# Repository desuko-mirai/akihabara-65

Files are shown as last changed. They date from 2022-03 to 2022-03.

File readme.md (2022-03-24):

# Akihabara 65 v0.4

### A 65% keyboard designed for JIS layout, with ANSI and ISO support.

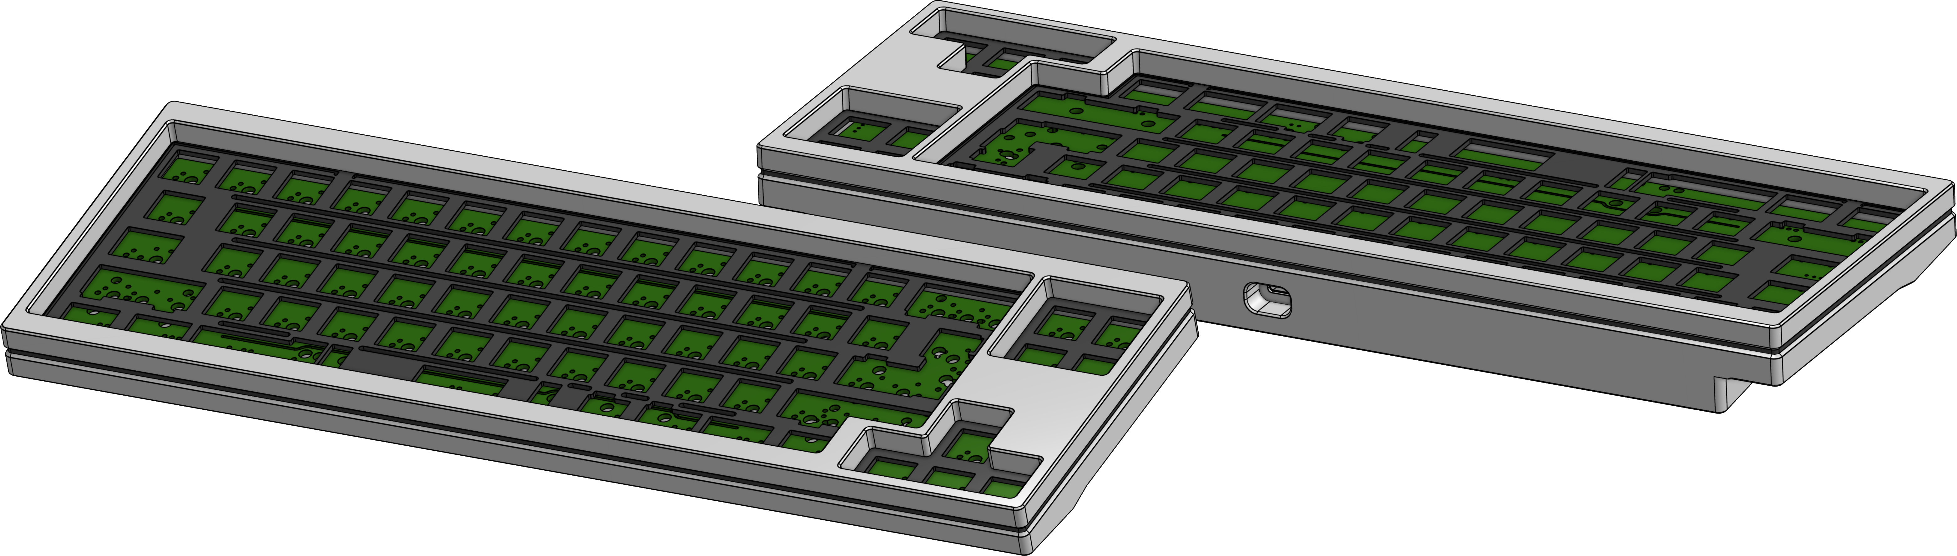
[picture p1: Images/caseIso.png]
Case Isometric


## Design Overview & Features

### Case

- 7° typing angle
- Modified sandwich mount
- 19 mm front height, 13.3 mm plate height @ bottom row, 22.6 mm plate height @ top row, all measurements with feet
- [SKUF](https://github.com/Zambumon/SKUF) Feet
- Approximately 1050 g with aluminium plate
- Exposed plate edges
- Plate features four rows of flex cuts, and the primary key cluster is separated from the plate save for four "mounting points" in an attempt to soften the harshness associated with sandwich mount
- 9.525 mm top and bottom bezels, 4.7625 mm side bezels
- 339 x 116 x 31 mm

### PCB

- Designed for STM32F072, but should be compatible with other STM32 models
- [Unified C3](https://github.com/ai03-2725/Unified-Daughterboard) Daughterboard
- QMK & VIA in progress
- PCB designed with KiCAD 6
- Bottom row legend; no more guessing where to place your switches and stabilizers
- Two flex cuts

## Layouts

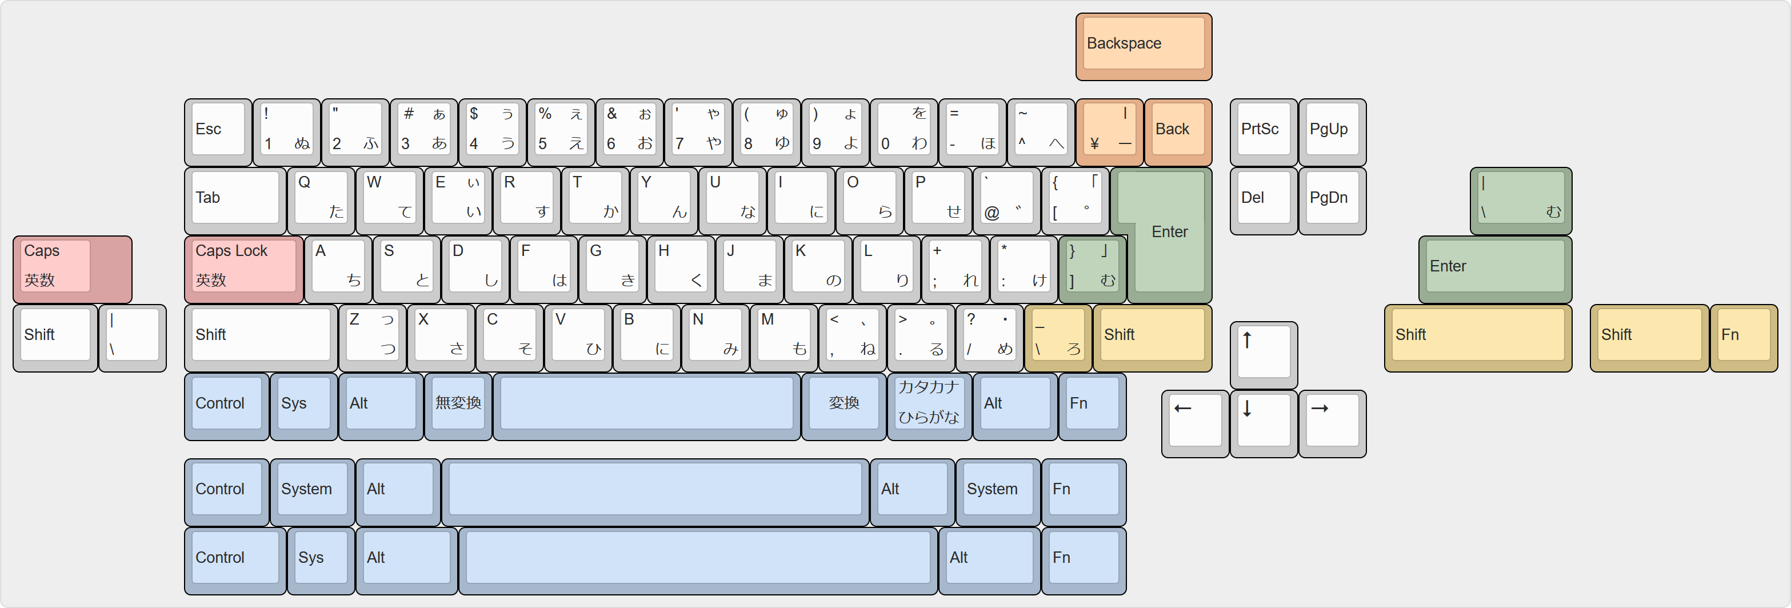
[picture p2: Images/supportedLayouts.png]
Supported Layouts


The Akihabara 65 was designed for a JIS layout with a 4.5u spacebar, but it supports many layouts. Options include:

- Standard or Stepped Caps Lock
- Standard or Split Backspace
- 2.75u or Split Right Shift (1.75u | 1u **OR** 1u | 1.75u)
- ANSI or ISO/JIS Enter
- 4.5u, 6.25u, or 7u Bottom Row

## Supported Keycap Sets

Almost all sets will support ANSI, and many support ISO as well, however JIS is significantly less common amongst custom keyboard enthusiasts, even in Japan. Still, keycap sets with JIS compatibility do exist. Known sets include:

- [ePBT SimpleJA R2](https://geekhack.org/index.php?topic=114422.0)[^kitting][^spacebar] by ai03
- [ePBT ModernJA](https://geekhack.org/index.php?topic=109341.0)[^kitting][^spacebar] by ai03
- [TMT Story](https://geekhack.org/index.php?topic=112681.0)[^gb] by shawnlyx/lunasho
- [GMK JIS](https://geekhack.org/index.php?topic=108328.0)[^gb] by 2Moons
- [Majestouch Keycaps](https://www.diatec.co.jp/products/list.php?s[]=100:1002:10008)[^fn] by FILCO/DIATEC

[^kitting]: Requires JIS/ISO kit
[^spacebar]: Does not include 4.5u spacebar
[^gb]: Group buy not yet fulfilled
[^fn]: Does not inclue R4 1u Fn key; can substitute with Menu key

### 4.5u Keycaps & Stabilizers

Outside of Japan, 4.5u spacebars are very uncommon; even more so in the quality we expect in this hobby. The selection is very limited, but not completely nonexistent.

The easiest way to acquire a 4.5u spacebar is to purchase one from KPRepublic [here](https://kprepublic.com/products/xda-blank-convex-spacebar-grey-1-75u-2u-2-25u-2-75u-3u-4-5u-5-5u-6u-6-25u-6-5u-7u-blank-keycaps-for-xd60-xd64-xd84-xd75-gh60-60). Unfortunately, these only come in grey PBT in XDA profile. An XDA spacebar does not look too out of place amongst Cherry-profile keycaps, and being PBT you can theoretically dye it. Signature Plastics also produces 4.5u spacebars in their SA profile, but these are unfortunately not sold on PMK, so acquiring one might prove difficult. TomatoCaps has a 4.5u spacebar mold, as seen in TMT Story. GMK will also have a 4.5u spacebar mold some time in 2022.

The only place I have found that sells 4.5u stabilizers is NPKC RGB CP Store on AliExpress. I purchased mine from their store [here](https://www.aliexpress.com/item/32855603554.html); just leave the seller a message on checkout saying you want 4.5u wires instead of 6.25u. I believe they will also sell you the wires by themselves; the housings are not very good at all, so this route may be preferable.

You can also make a 4.5u wire yourself by cutting and bending a 6.25u or 7u wire (or any wire longer than 4.5u). The centre-to-centre distance of the stabilizer mounts on a 4.5u spacebar is 69.342 mm. It is difficult to get the bend radius tight without a wire bender, but that still did not cause any issues with the Durock wire I bent.

## And A Big "Thank You" To:

- **kkatano** for the [Bakeneko](https://github.com/kkatano/bakeneko-65), from which I took many design elements for the case (and it's also just a really nice keyboard)
- **4pplet** and **Gondolindrim** for sharing their knowledge of ARM-powered keyboards in a world filled with AVR
- **ai03** for their brilliant [plate generator](https://kbplate.ai03.com/) and [keyswitch footprints](https://github.com/ai03-2725/MX_Alps_Hybrid), as well as their [PCB design guide](https://wiki.ai03.com/books/pcb-design)
- **hadi** for their [PCB design series](https://www.youtube.com/watch?v=BhFqkVggv8Q), unfinished as it may be
- **2Moons** for helping me confirm dimensions for 4.5u spacebars

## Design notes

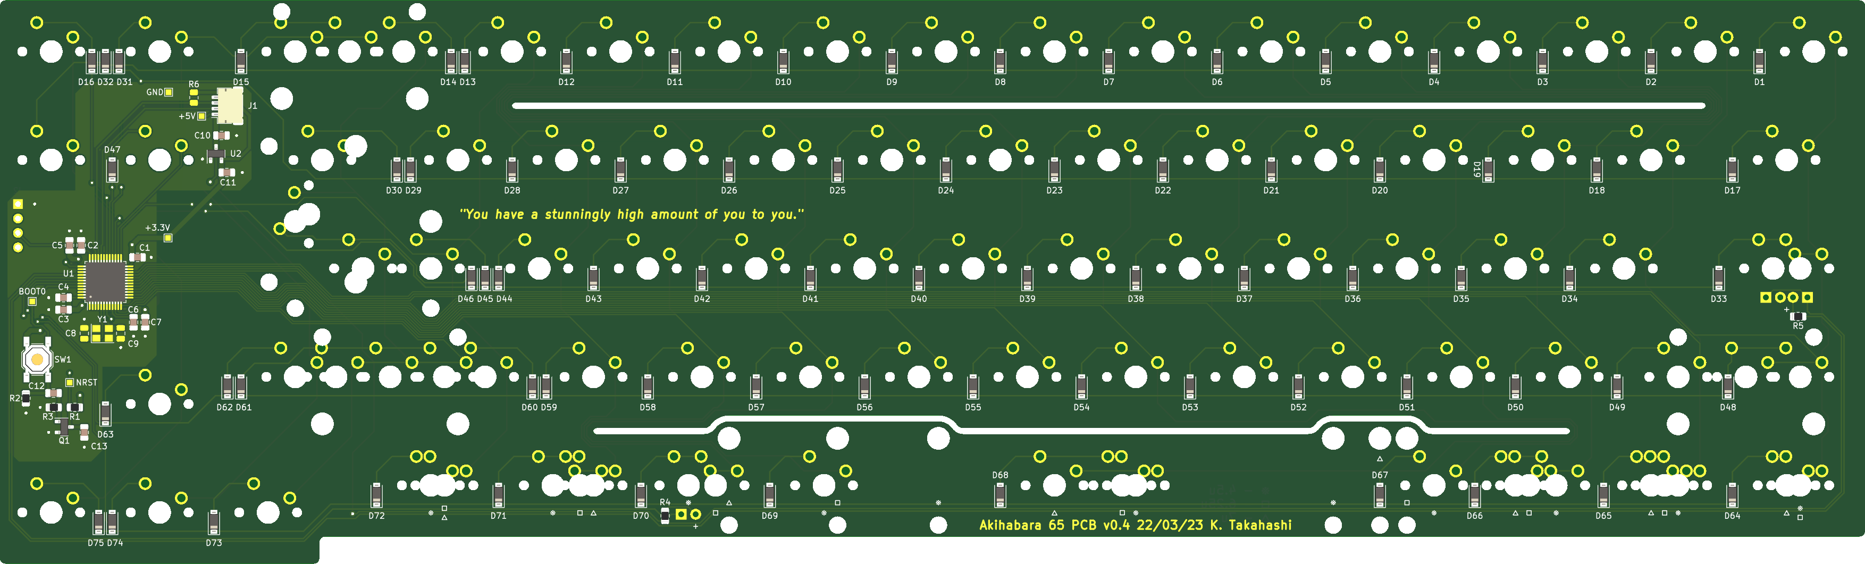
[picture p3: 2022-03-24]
Images/boardBack.png

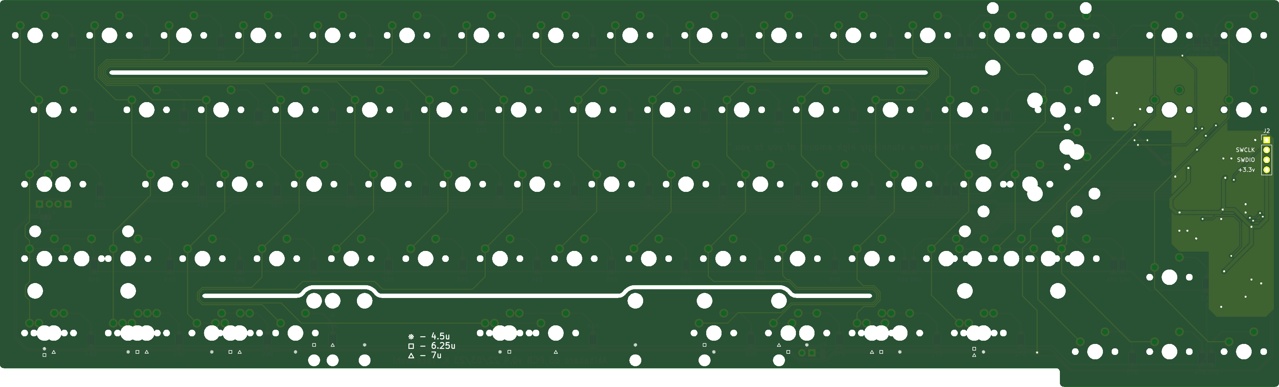
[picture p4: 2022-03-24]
Images/boardFront.png

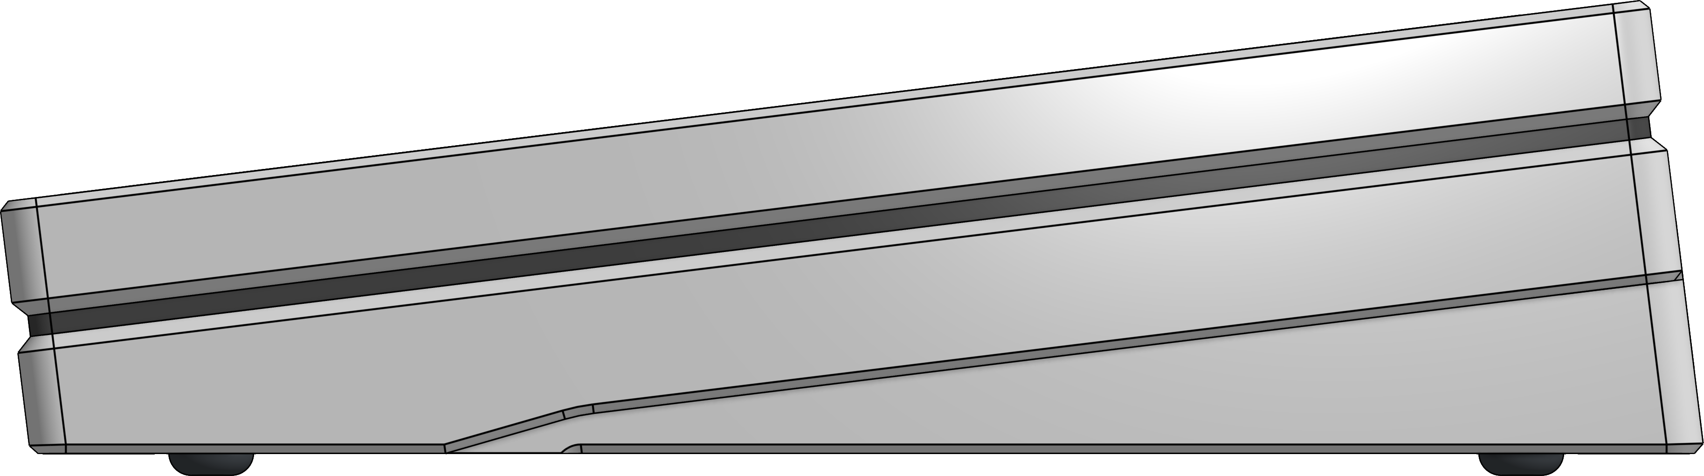
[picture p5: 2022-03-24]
Images/caseSide.png

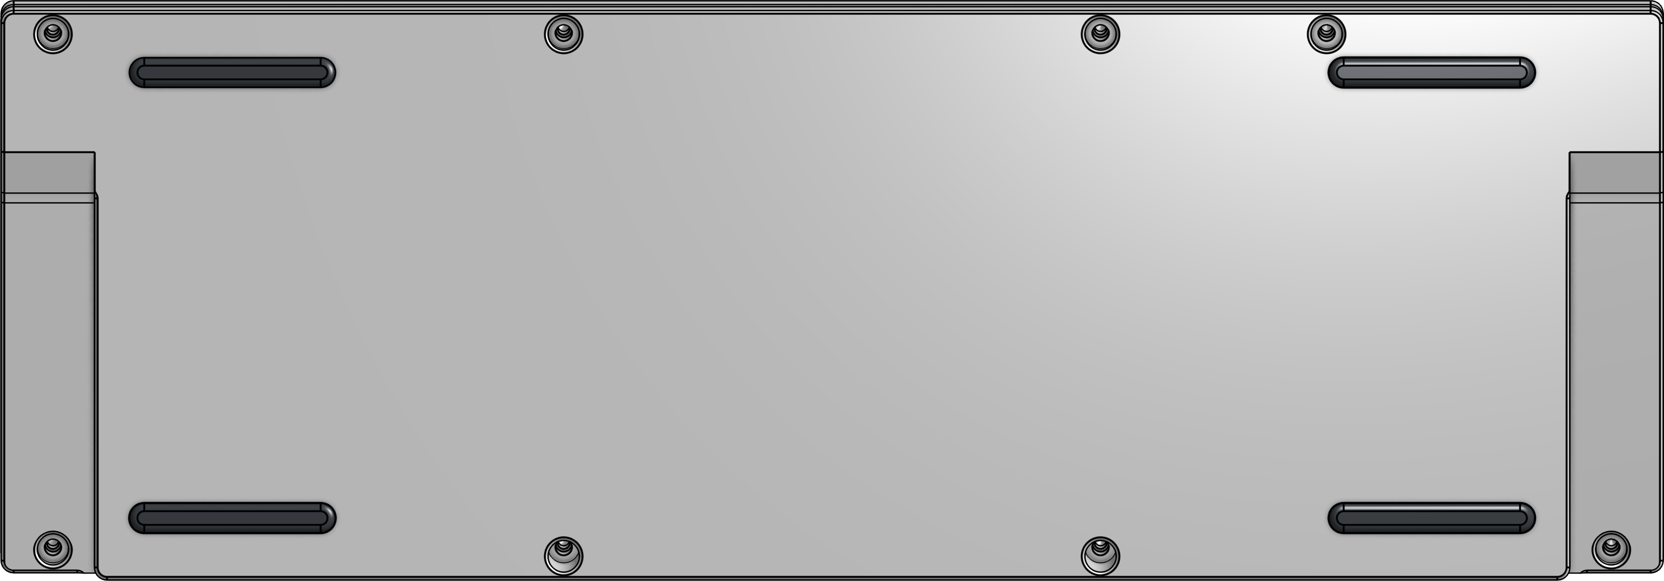
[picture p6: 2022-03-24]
Images/caseBottom.png

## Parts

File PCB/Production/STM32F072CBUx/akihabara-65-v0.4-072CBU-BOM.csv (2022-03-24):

Comment | Designator | Footprint | LCSC
100nF | C1,C2,C3 | Capacitor_SMD:C_0805_2012Metric | C28233
4.7uF | C4,C5,C12 | Capacitor_SMD:C_0805_2012Metric | C1779
10nF | C6 | Capacitor_SMD:C_0805_2012Metric | C1710
1uF | C7,C10,C11,C13 | Capacitor_SMD:C_0805_2012Metric | C28323
1N4148W | D1,D2,D3,D4,D5,D6,D7,D8,D9,D10,D11,D12,D13,D14,D15,D16,D17,D18,D19,D20,D21,D22,D23,D24,D25,D26,D27,D28,D29,D30,D31,D32,D33,D34,D35,D36,D37,D38,D39,D40,D41,D42,D43,D44,D45,D46,D47,D48,D49,D50,D51,D52,D53,D54,D55,D56,D57,D58,D59,D60,D61,D62,D63,D64,D65,D66,D67,D68,D69,D70,D71,D72,D73,D74,D75 | Diode_SMD:D_SOD-123 | C81598
SM04B-SRSS-TB(LF)(SN) | J1 | Connector_JST:JST_SH_SM04B-SRSS-TB_1x04-1MP_P1.00mm_Horizontal | C160404
2N7002 | Q1 | Package_TO_SOT_SMD:SOT-23 | C8545
10k | R1,R2 | Resistor_SMD:R_0805_2012Metric | C17414
100k | R3 | Resistor_SMD:R_0805_2012Metric | C17407
220 | R4,R5 | Resistor_SMD:R_0805_2012Metric | C17557
TS-1187A-B-A-B | SW1 | Button_Switch_SMD:SW_SPST_TL3342 | C318884
STM32F072CBU6 | U1 | Akihabara_Footprints:STM32_CxT_CxU_Hybrid | C92504
XC6206P332MR | U2 | Package_TO_SOT_SMD:SOT-23 | C5446

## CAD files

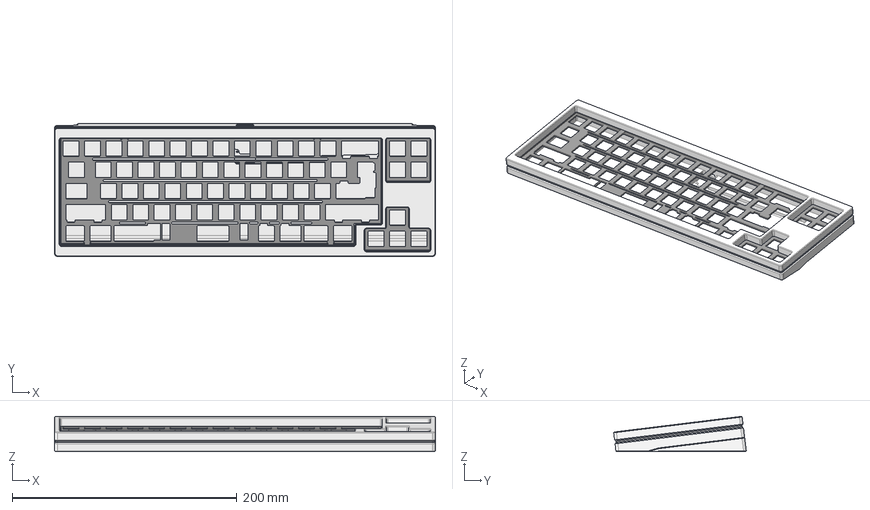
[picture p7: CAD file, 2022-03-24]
Case/akihabara-65-case-assembly-v0.4.step
339.1 x 118.1 x 31.3 mm
Plate
Case Top
Case Bottom

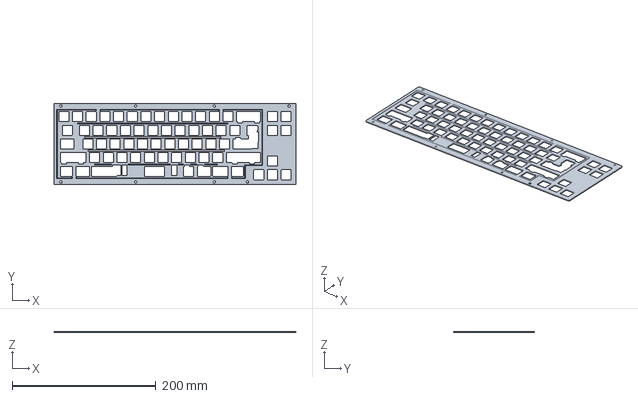
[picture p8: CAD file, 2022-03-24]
Plate/akihabara-65-plate-universal-v0.4.step
337.1 x 113.2 x 1.50 mm

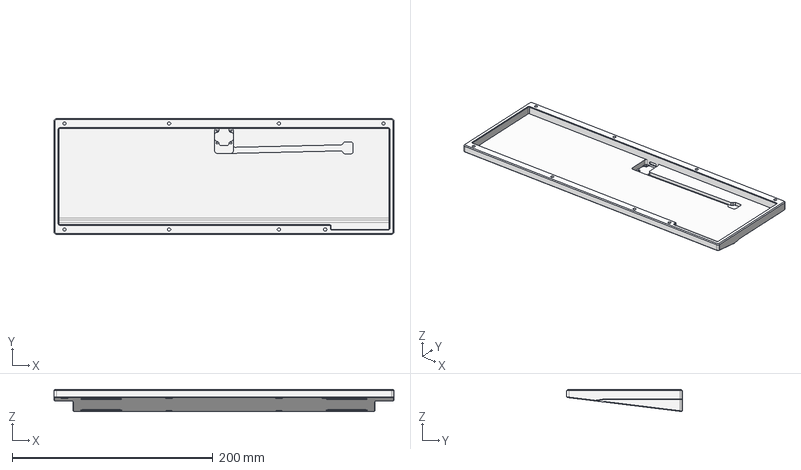
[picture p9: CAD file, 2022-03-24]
Case/akihabara-65-case-bottom-v0.4.step
339.1 x 115.2 x 22.1 mm

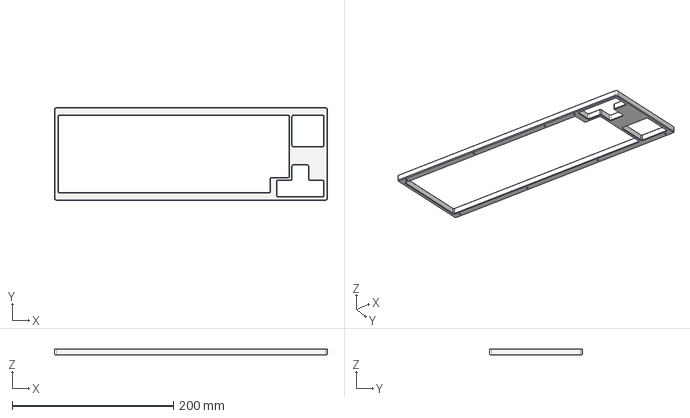
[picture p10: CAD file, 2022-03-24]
Case/akihabara-65-case-top-v0.4.step
339.1 x 115.2 x 8.00 mm

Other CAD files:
Plate/akihabara-65-plate-universal-v0.4.dxf

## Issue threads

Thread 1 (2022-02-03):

Stabilizer holes too small

desuko-mirai, 2022-02-03:
The larger of the two holes used to mount the stabilizers are too small, making inserting the stabilizer excessively difficult.

desuko-mirai, 2022-03-17:
Holes are correct and follow Cherry specifications; this was an issue caused by Durock stabs.

Closed 2022-03-17.

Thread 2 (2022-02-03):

ANSI Enter and Right Shift stabilizers mutually exclusive

desuko-mirai, 2022-02-03:
The ANSI Enter stabilizer is wire-down and the Right Shift stabilizer is wire-up, causing interference between the two stabilizers. Both stabilizers will be wire-down in v0.4.

desuko-mirai, 2022-03-17:
v0.4 now has north-facing ANSI Enter wire and south-facing Right Shift wire.

Closed 2022-03-17.

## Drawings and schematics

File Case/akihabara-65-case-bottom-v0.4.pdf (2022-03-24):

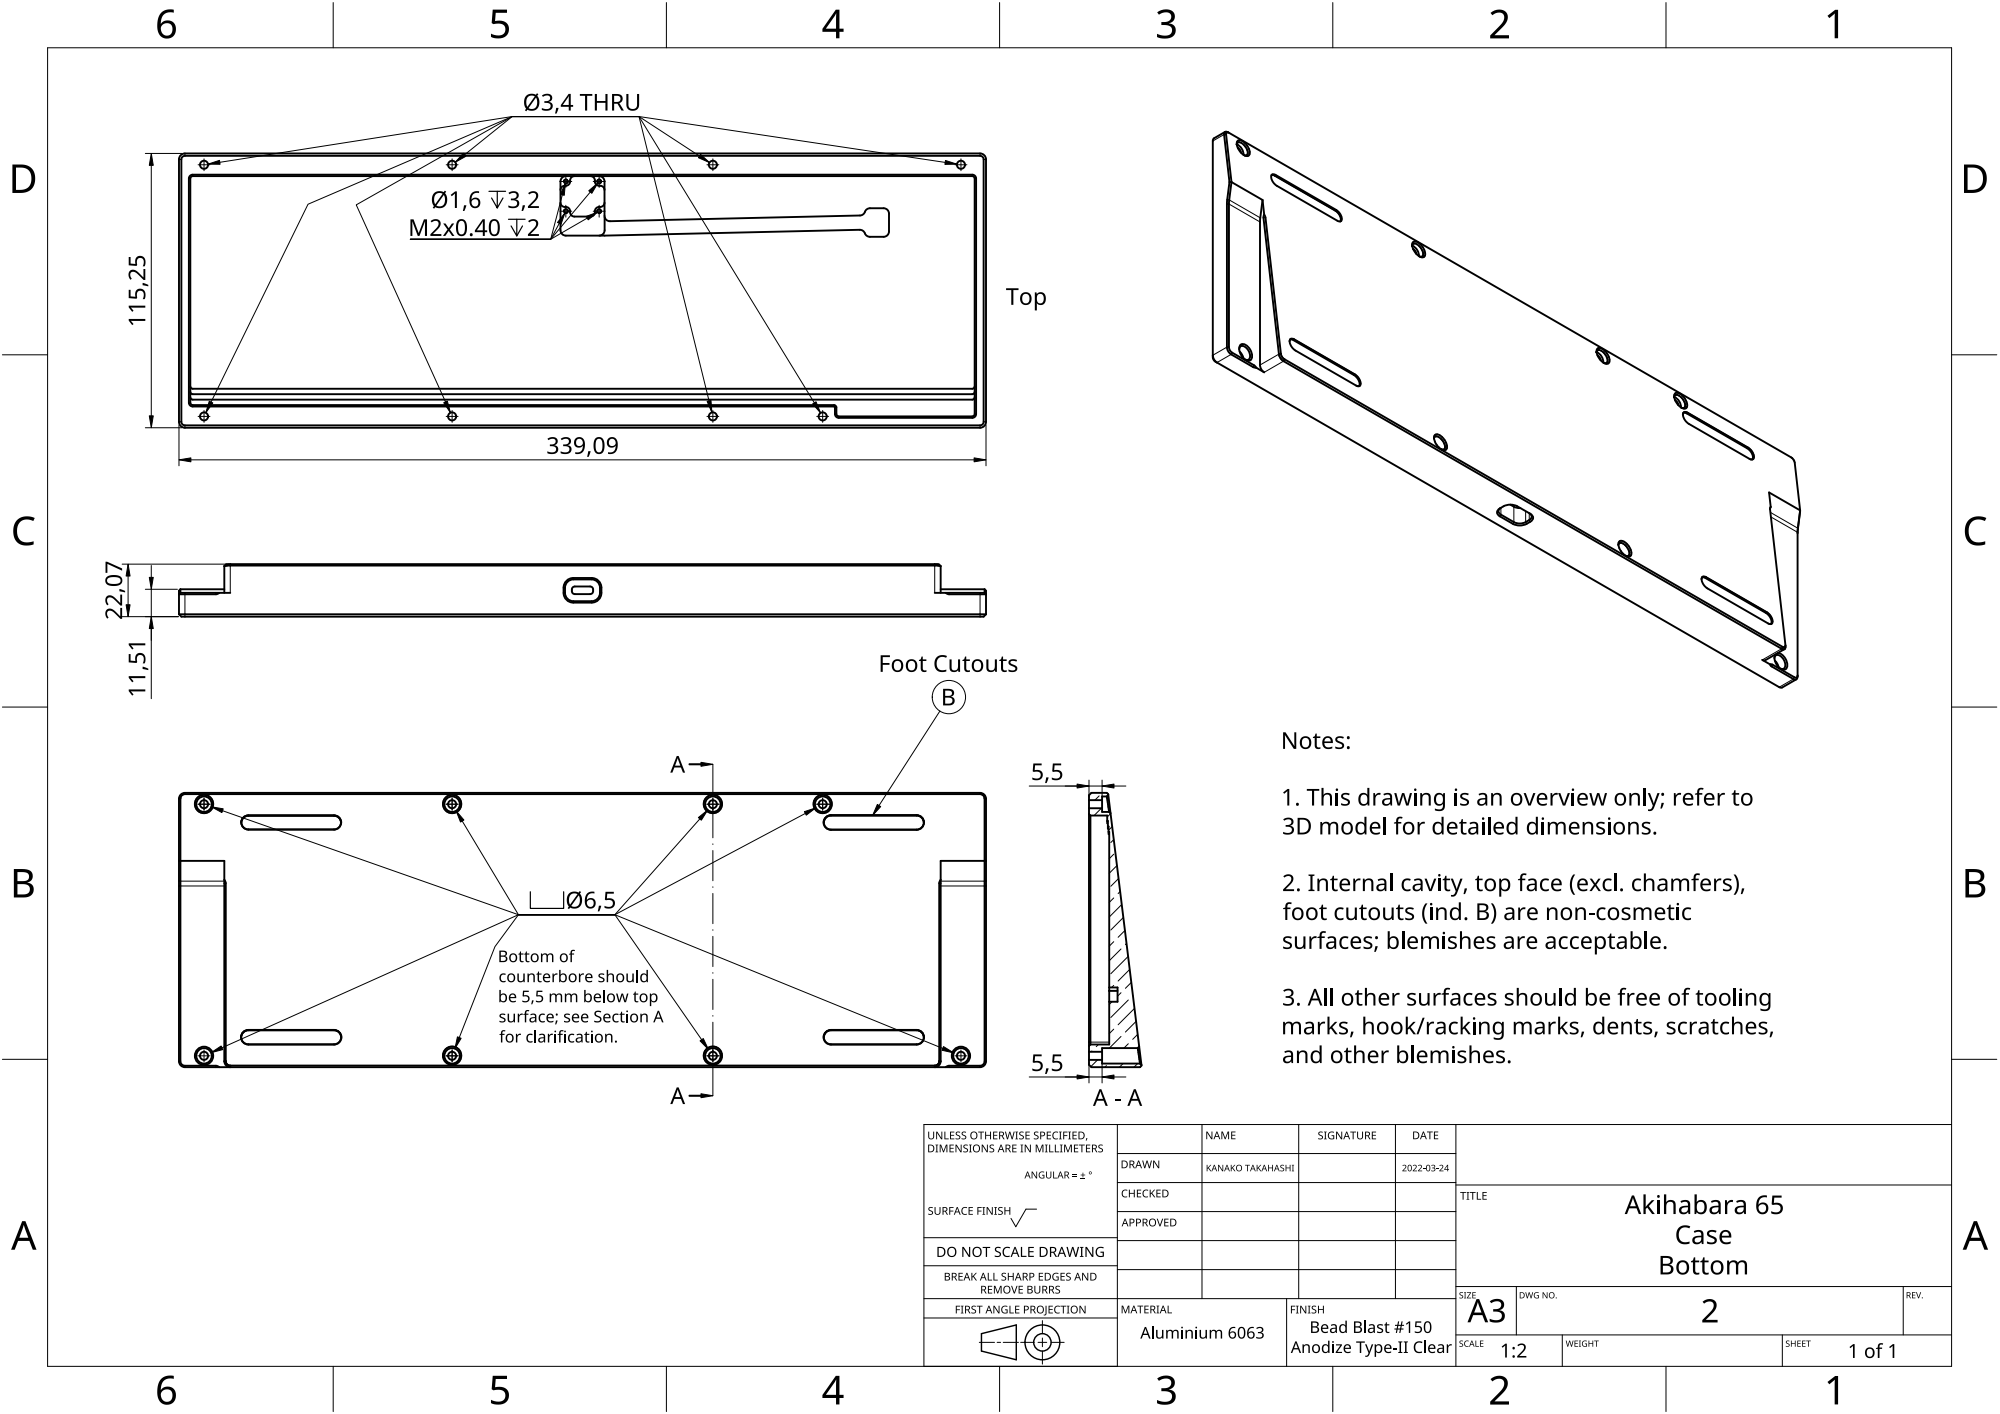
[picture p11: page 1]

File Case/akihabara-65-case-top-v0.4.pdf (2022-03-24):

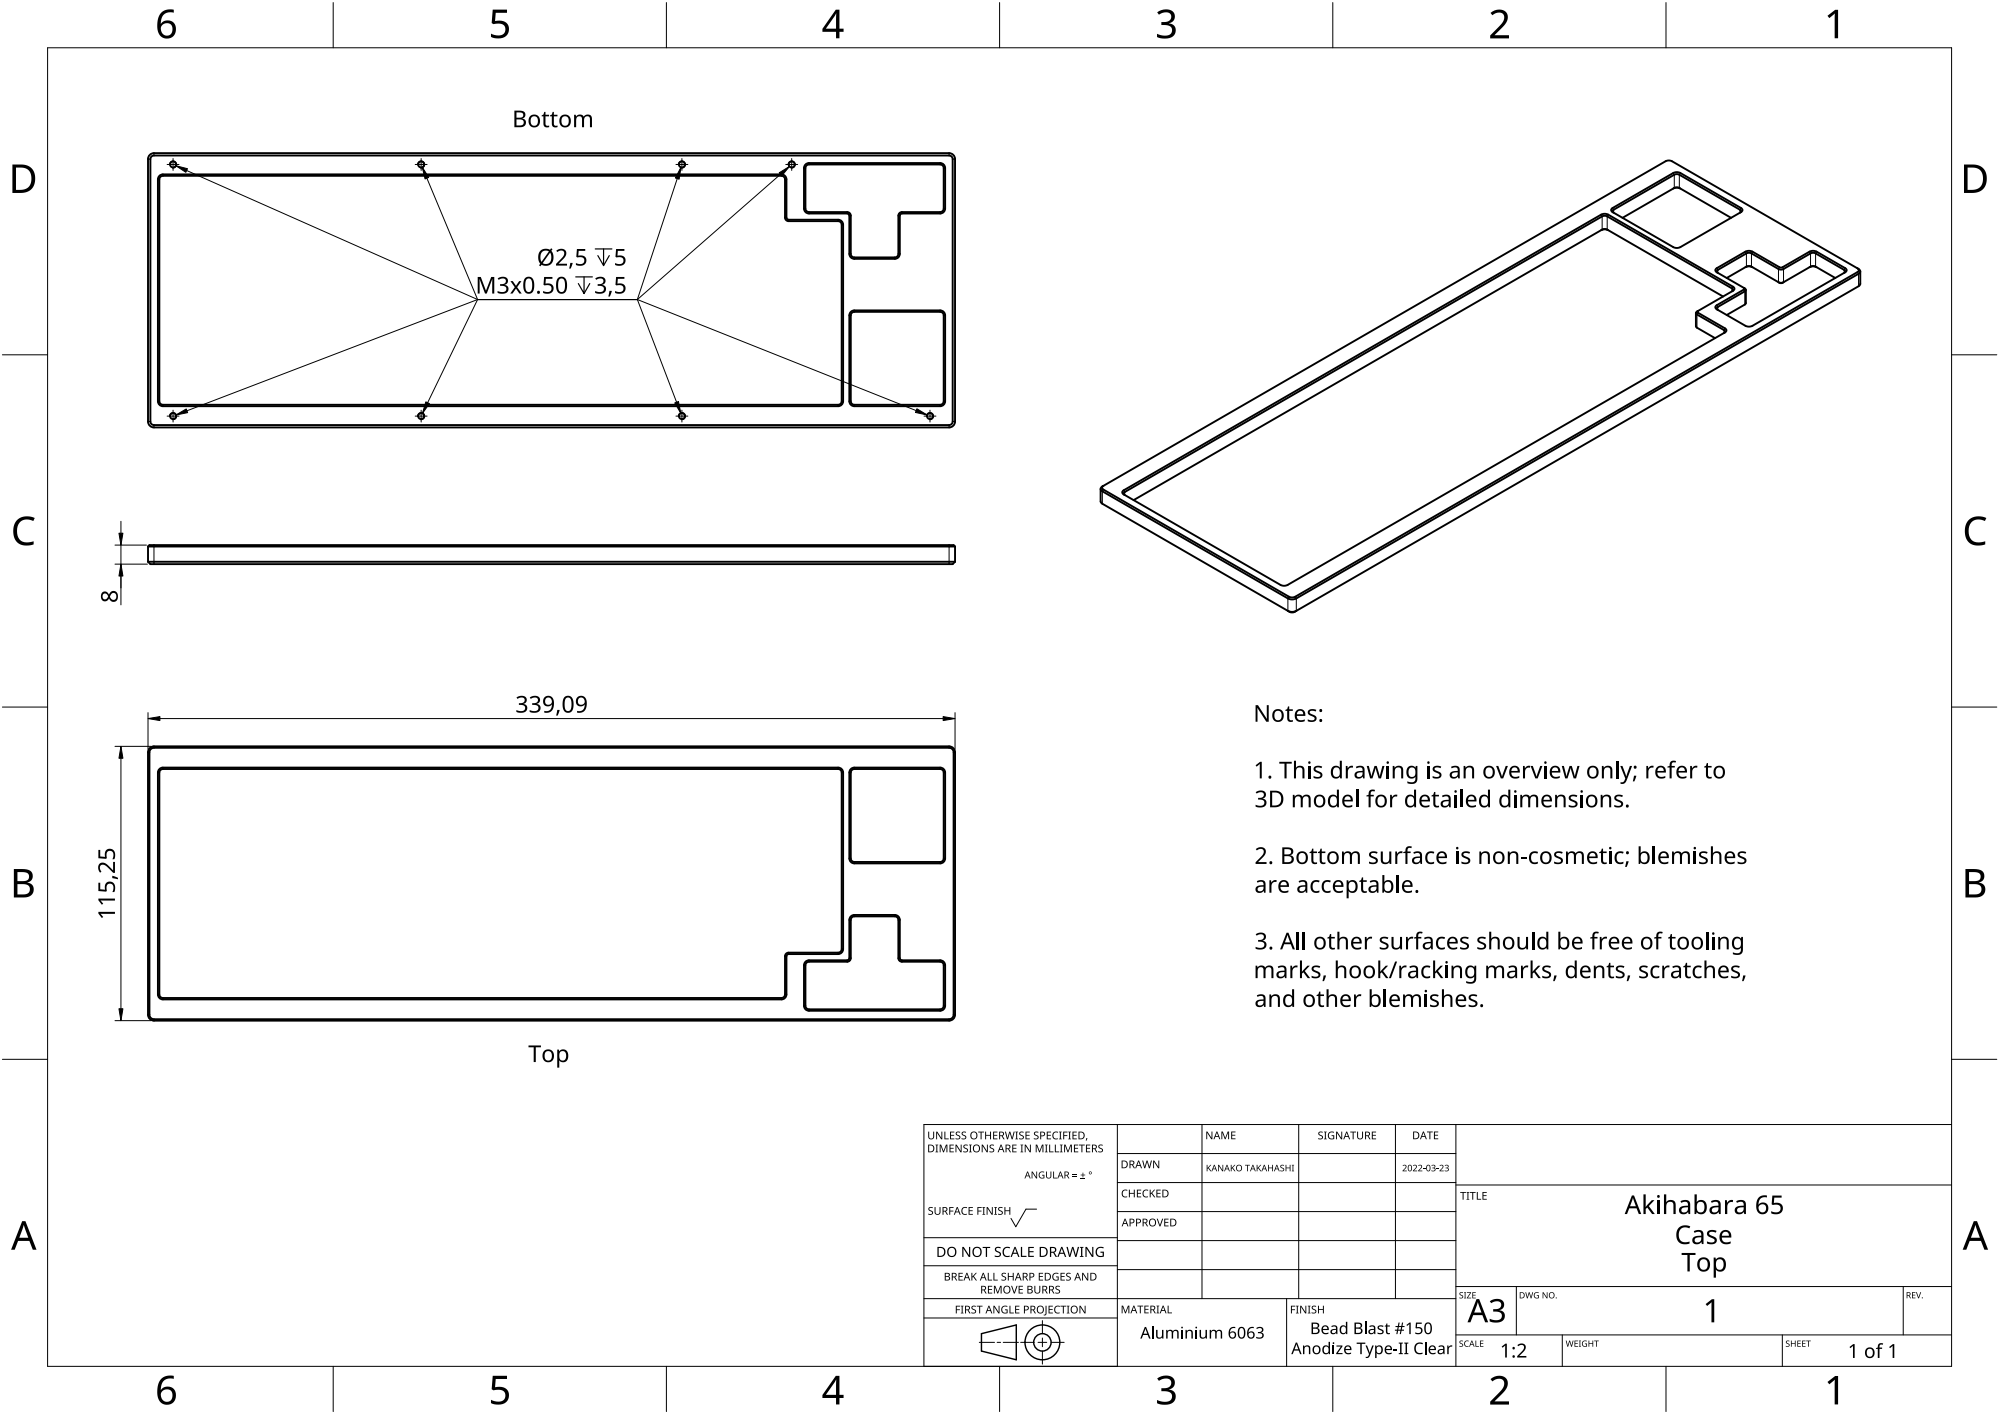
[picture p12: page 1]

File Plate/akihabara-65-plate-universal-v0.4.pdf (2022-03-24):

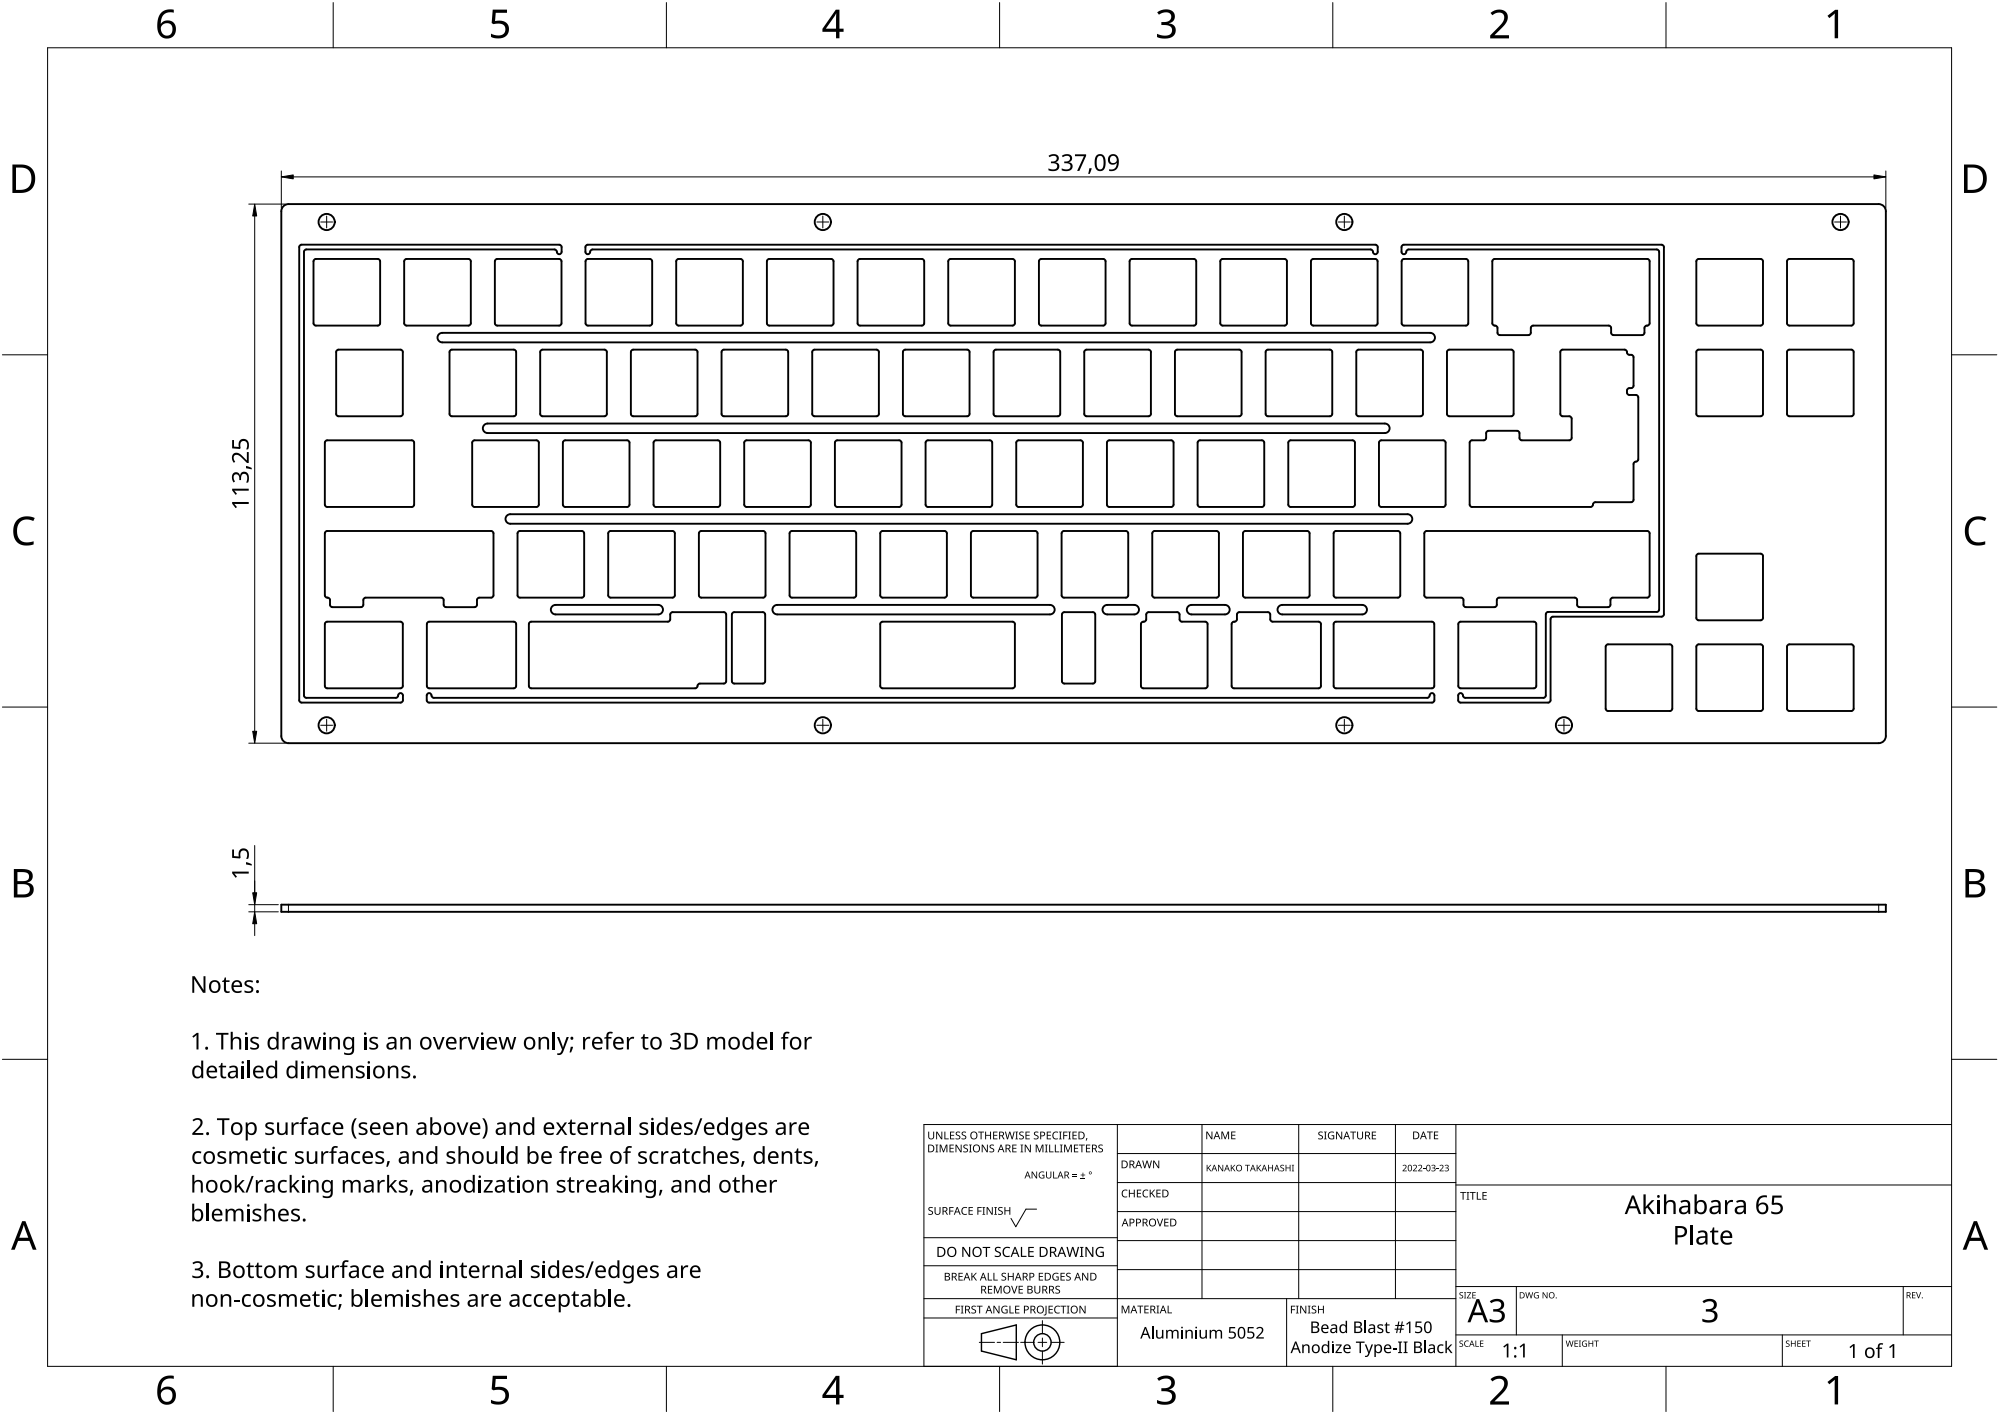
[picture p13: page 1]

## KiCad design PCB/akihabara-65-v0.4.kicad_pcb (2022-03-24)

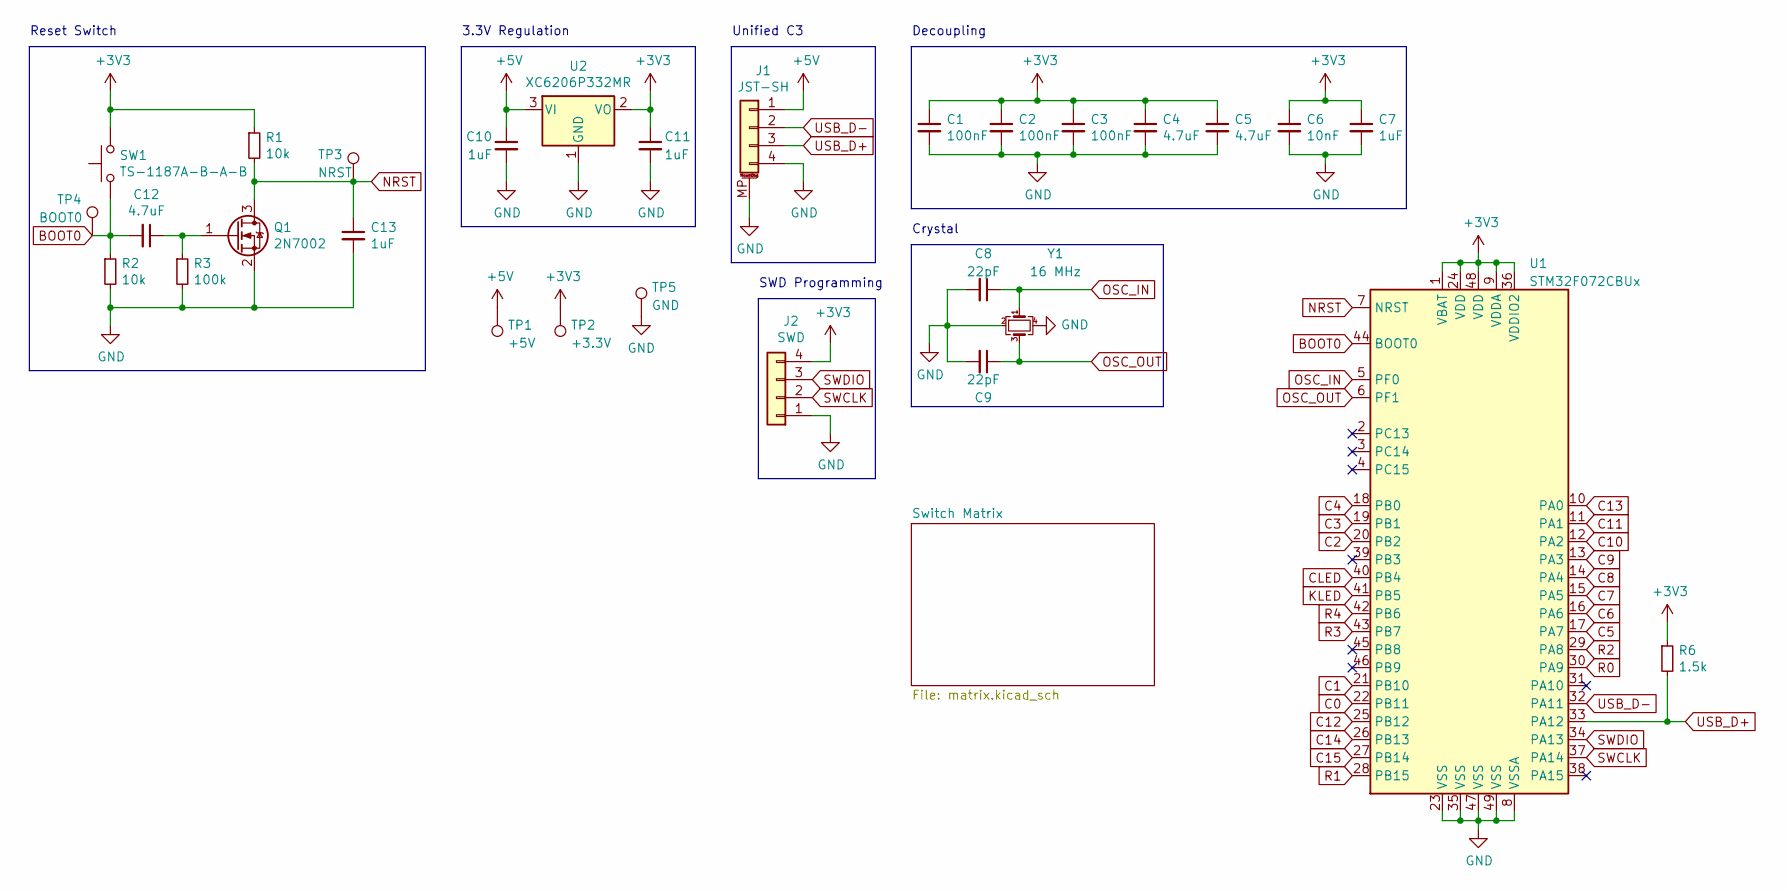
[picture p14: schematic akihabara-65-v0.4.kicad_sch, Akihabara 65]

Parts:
C1, C2, C3: 100nF; C_0805_2012Metric; LCSC C28233
C4, C5, C12: 4.7uF; C_0805_2012Metric; LCSC C1779
C6: 10nF; C_0805_2012Metric; LCSC C1710
C7, C10, C11, C13: 1uF; C_0805_2012Metric; LCSC C28323
C8, C9: 22pF; C_0805_2012Metric; LCSC C1804
J1: JST-SH; JST_SH_SM04B-SRSS-TB_1x04-1MP_P1.00mm_Horizontal; LCSC C160404
J2: SWD; PinHeader_1x04_P2.54mm_Vertical
Q1: 2N7002; SOT-23; LCSC C8545
R1, R2: 10k; R_0805_2012Metric; LCSC C17414
R3: 100k; R_0805_2012Metric; LCSC C17407
R6: 1.5k; R_0805_2012Metric; LCSC C4310
SW1: TS-1187A-B-A-B; SW_SPST_TL3342; LCSC C318884
TP1: +5V; TestPoint_Pad_1.0x1.0mm
TP2: +3.3V; TestPoint_Pad_1.0x1.0mm
TP3: NRST; TestPoint_Pad_1.0x1.0mm
TP4: BOOT0; TestPoint_Pad_1.0x1.0mm
TP5: GND; TestPoint_Pad_1.0x1.0mm
U1: STM32F072CBUx; STM32_CxT_CxU_Hybrid; LCSC C92504
U2: XC6206P332MR; SOT-23; LCSC C5446
Y1: 16 MHz; Crystal_SMD_3225-4Pin_3.2x2.5mm; LCSC C13738

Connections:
+3V3: C1.1, C2.1, C3.1, C4.1, C5.1, C6.1, C7.1, C11.1, J2.4, R1.1, R6.1, SW1.2, TP2.1, U1.1 (VBAT), U1.9 (VDDA), U1.24 (VDD), U1.36 (VDDIO2), U1.48 (VDD), U2.2 (VO)
+5V: C10.1, J1.1, TP1.1, U2.3 (VI); also elsewhere on the board
BOOT0: C12.2, R2.1, SW1.1, TP4.1, U1.44 (BOOT0)
C0: U1.22 (PB11); also elsewhere on the board
C1: U1.21 (PB10); also elsewhere on the board
C2: U1.20 (PB2); also elsewhere on the board
C3: U1.19 (PB1); also elsewhere on the board
C4: U1.18 (PB0); also elsewhere on the board
C5: U1.17 (PA7); also elsewhere on the board
C6: U1.16 (PA6); also elsewhere on the board
C7: U1.15 (PA5); also elsewhere on the board
C8: U1.14 (PA4); also elsewhere on the board
C9: U1.13 (PA3); also elsewhere on the board
C10: U1.12 (PA2); also elsewhere on the board
C11: U1.11 (PA1); also elsewhere on the board
C12: U1.25 (PB12); also elsewhere on the board
C13: U1.10 (PA0); also elsewhere on the board
C14: U1.26 (PB13); also elsewhere on the board
C15: U1.27 (PB14); also elsewhere on the board
CLED: U1.40 (PB4); also elsewhere on the board
GND: C1.2, C2.2, C3.2, C4.2, C5.2, C6.2, C7.2, C8.2, C9.2, C10.2, C11.2, C13.2, J1.4, J1.MP (MountPin), J2.1, Q1.2 (S), R2.2, R3.2, TP5.1, U1.8 (VSSA), U1.23 (VSS), U1.35 (VSS), U1.47 (VSS), U1.49 (VSS), U2.1 (GND), Y1.2, Y1.4
KLED: U1.41 (PB5); also elsewhere on the board
NRST: C13.1, Q1.3 (D), R1.2, TP3.1, U1.7 (NRST)
unnamed: C12.1, Q1.1 (G), R3.1
OSC_IN: C8.1, U1.5 (PF0), Y1.1
OSC_OUT: C9.1, U1.6 (PF1), Y1.3
R0: U1.30 (PA9); also elsewhere on the board
R1: U1.28 (PB15); also elsewhere on the board
R2: U1.29 (PA8); also elsewhere on the board
R3: U1.43 (PB7); also elsewhere on the board
R4: U1.42 (PB6); also elsewhere on the board
SWCLK: J2.2, U1.37 (PA14)
SWDIO: J2.3, U1.34 (PA13)
USB_D+: J1.3, R6.2, U1.33 (PA12)
USB_D-: J1.2, U1.32 (PA11)

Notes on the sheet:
Reset Switch
3.3V Regulation
SWD Programming
Decoupling
Crystal
Unified C3

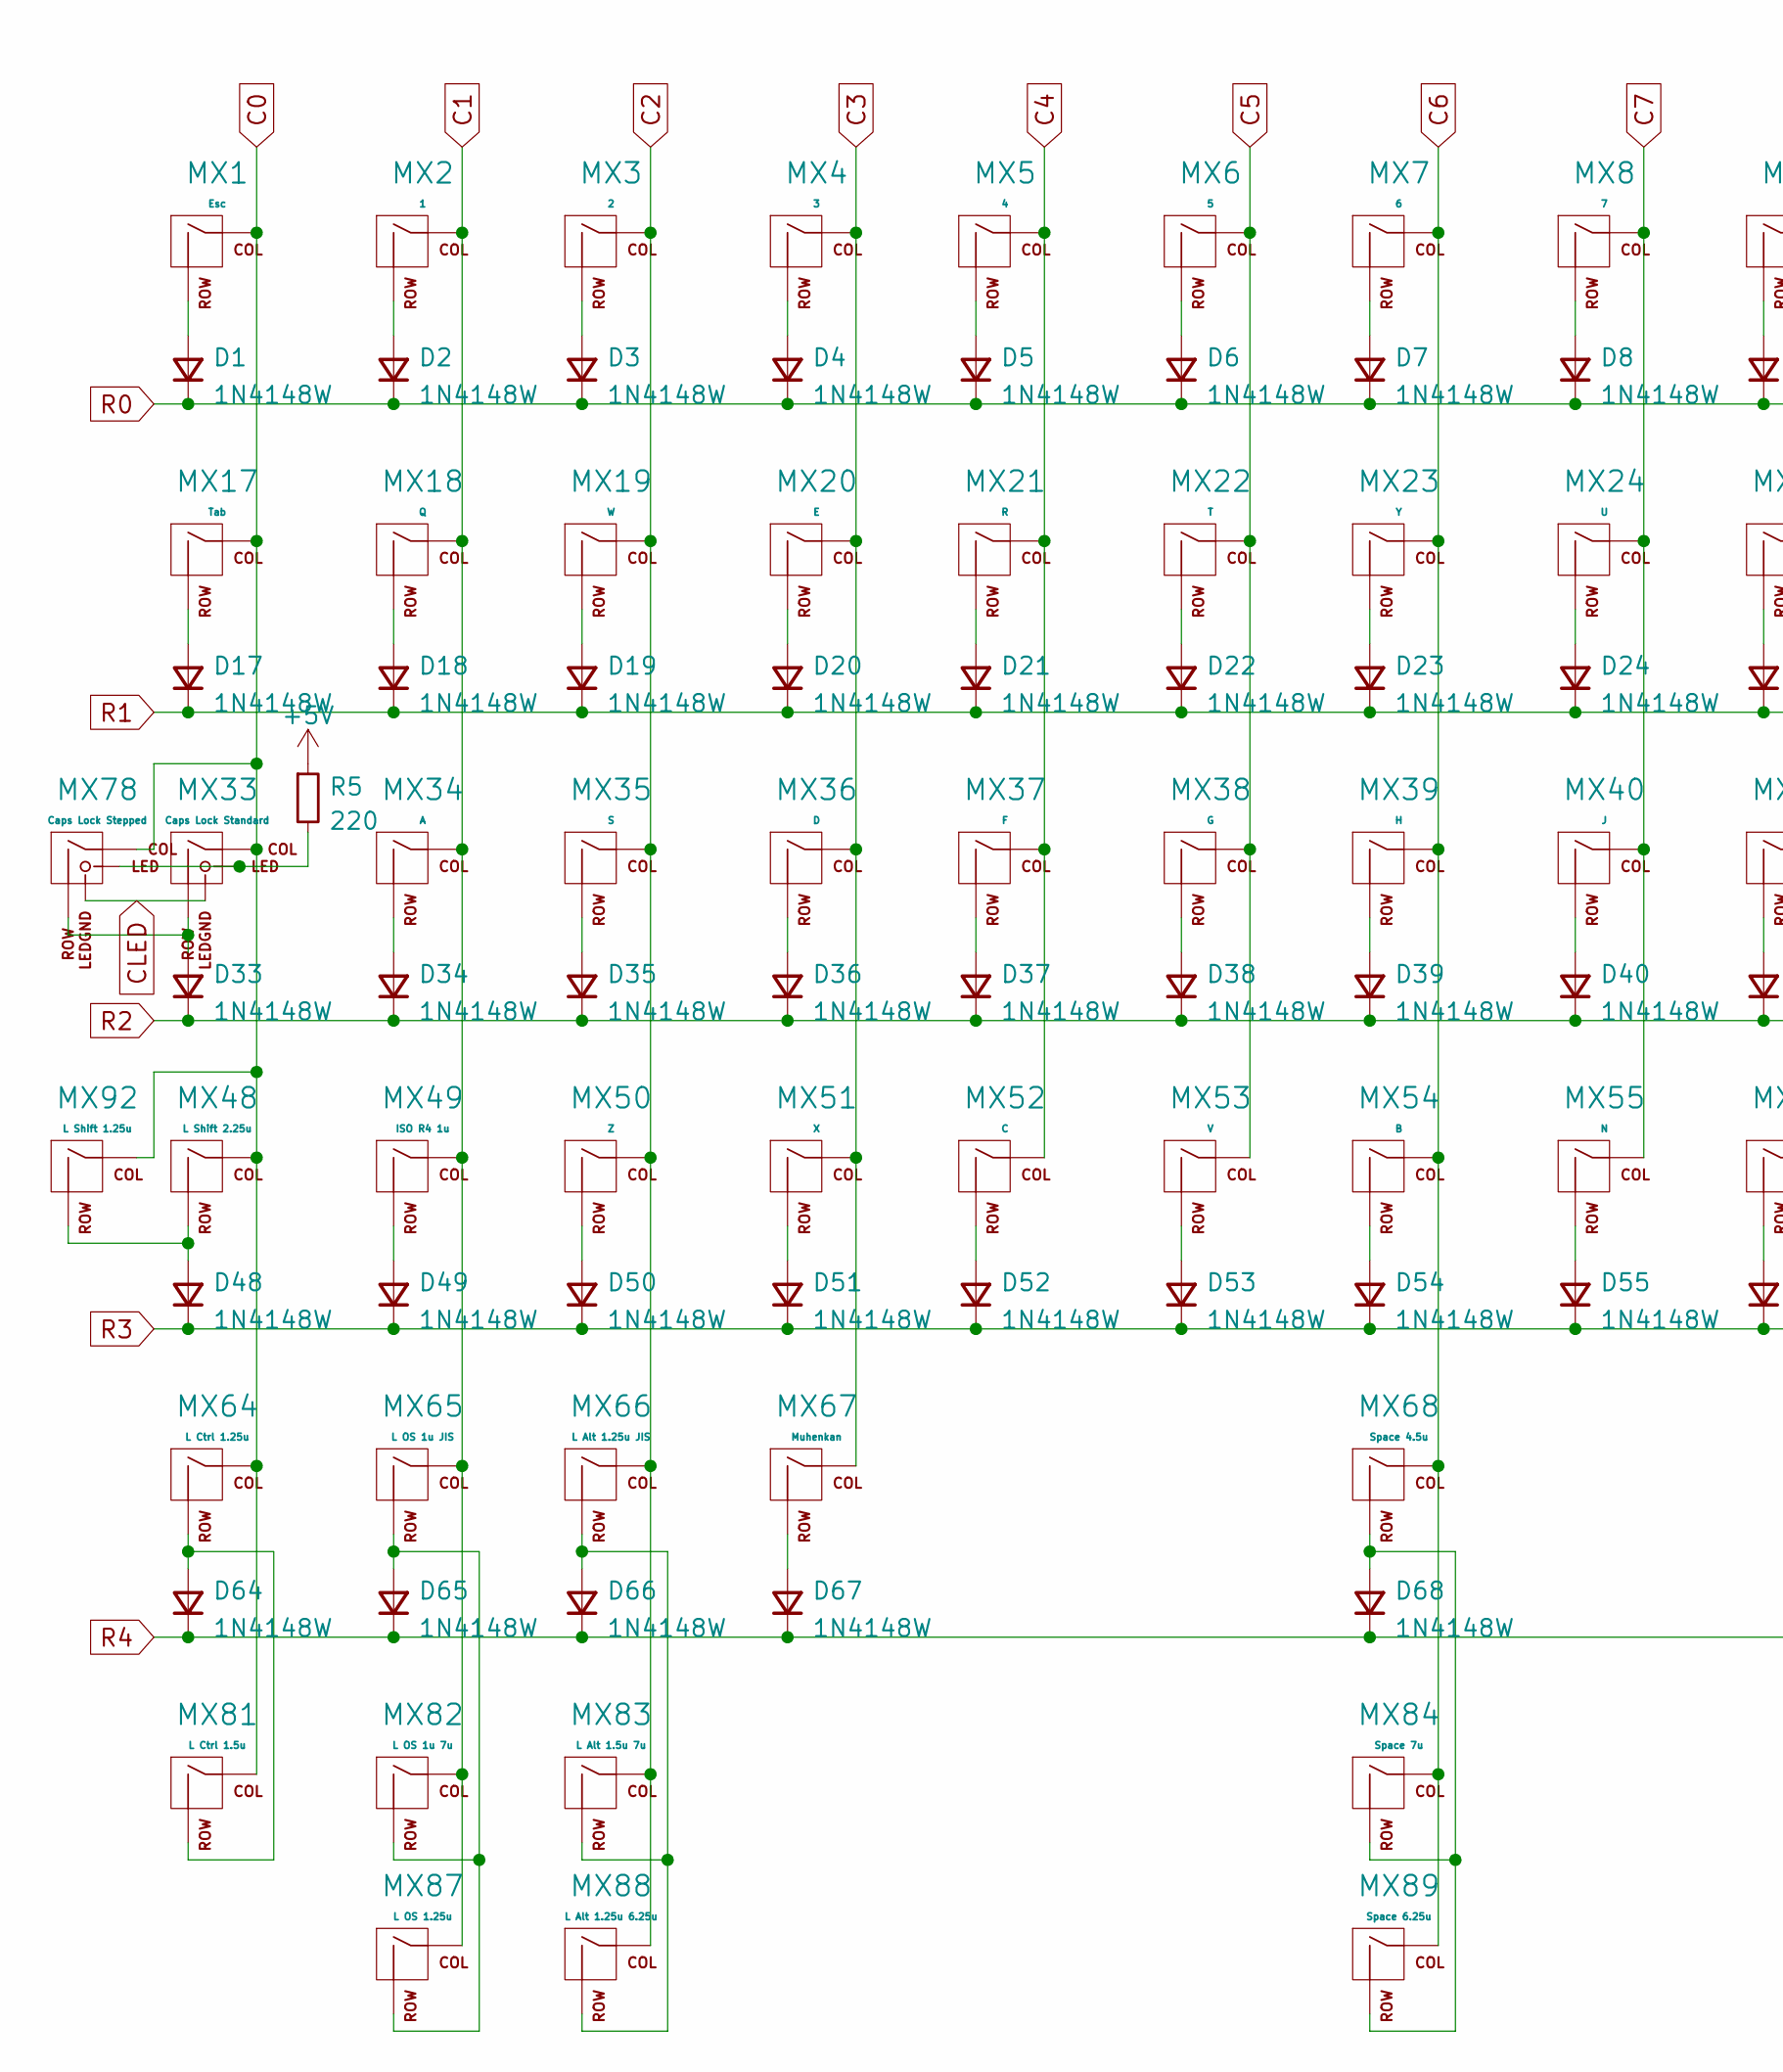
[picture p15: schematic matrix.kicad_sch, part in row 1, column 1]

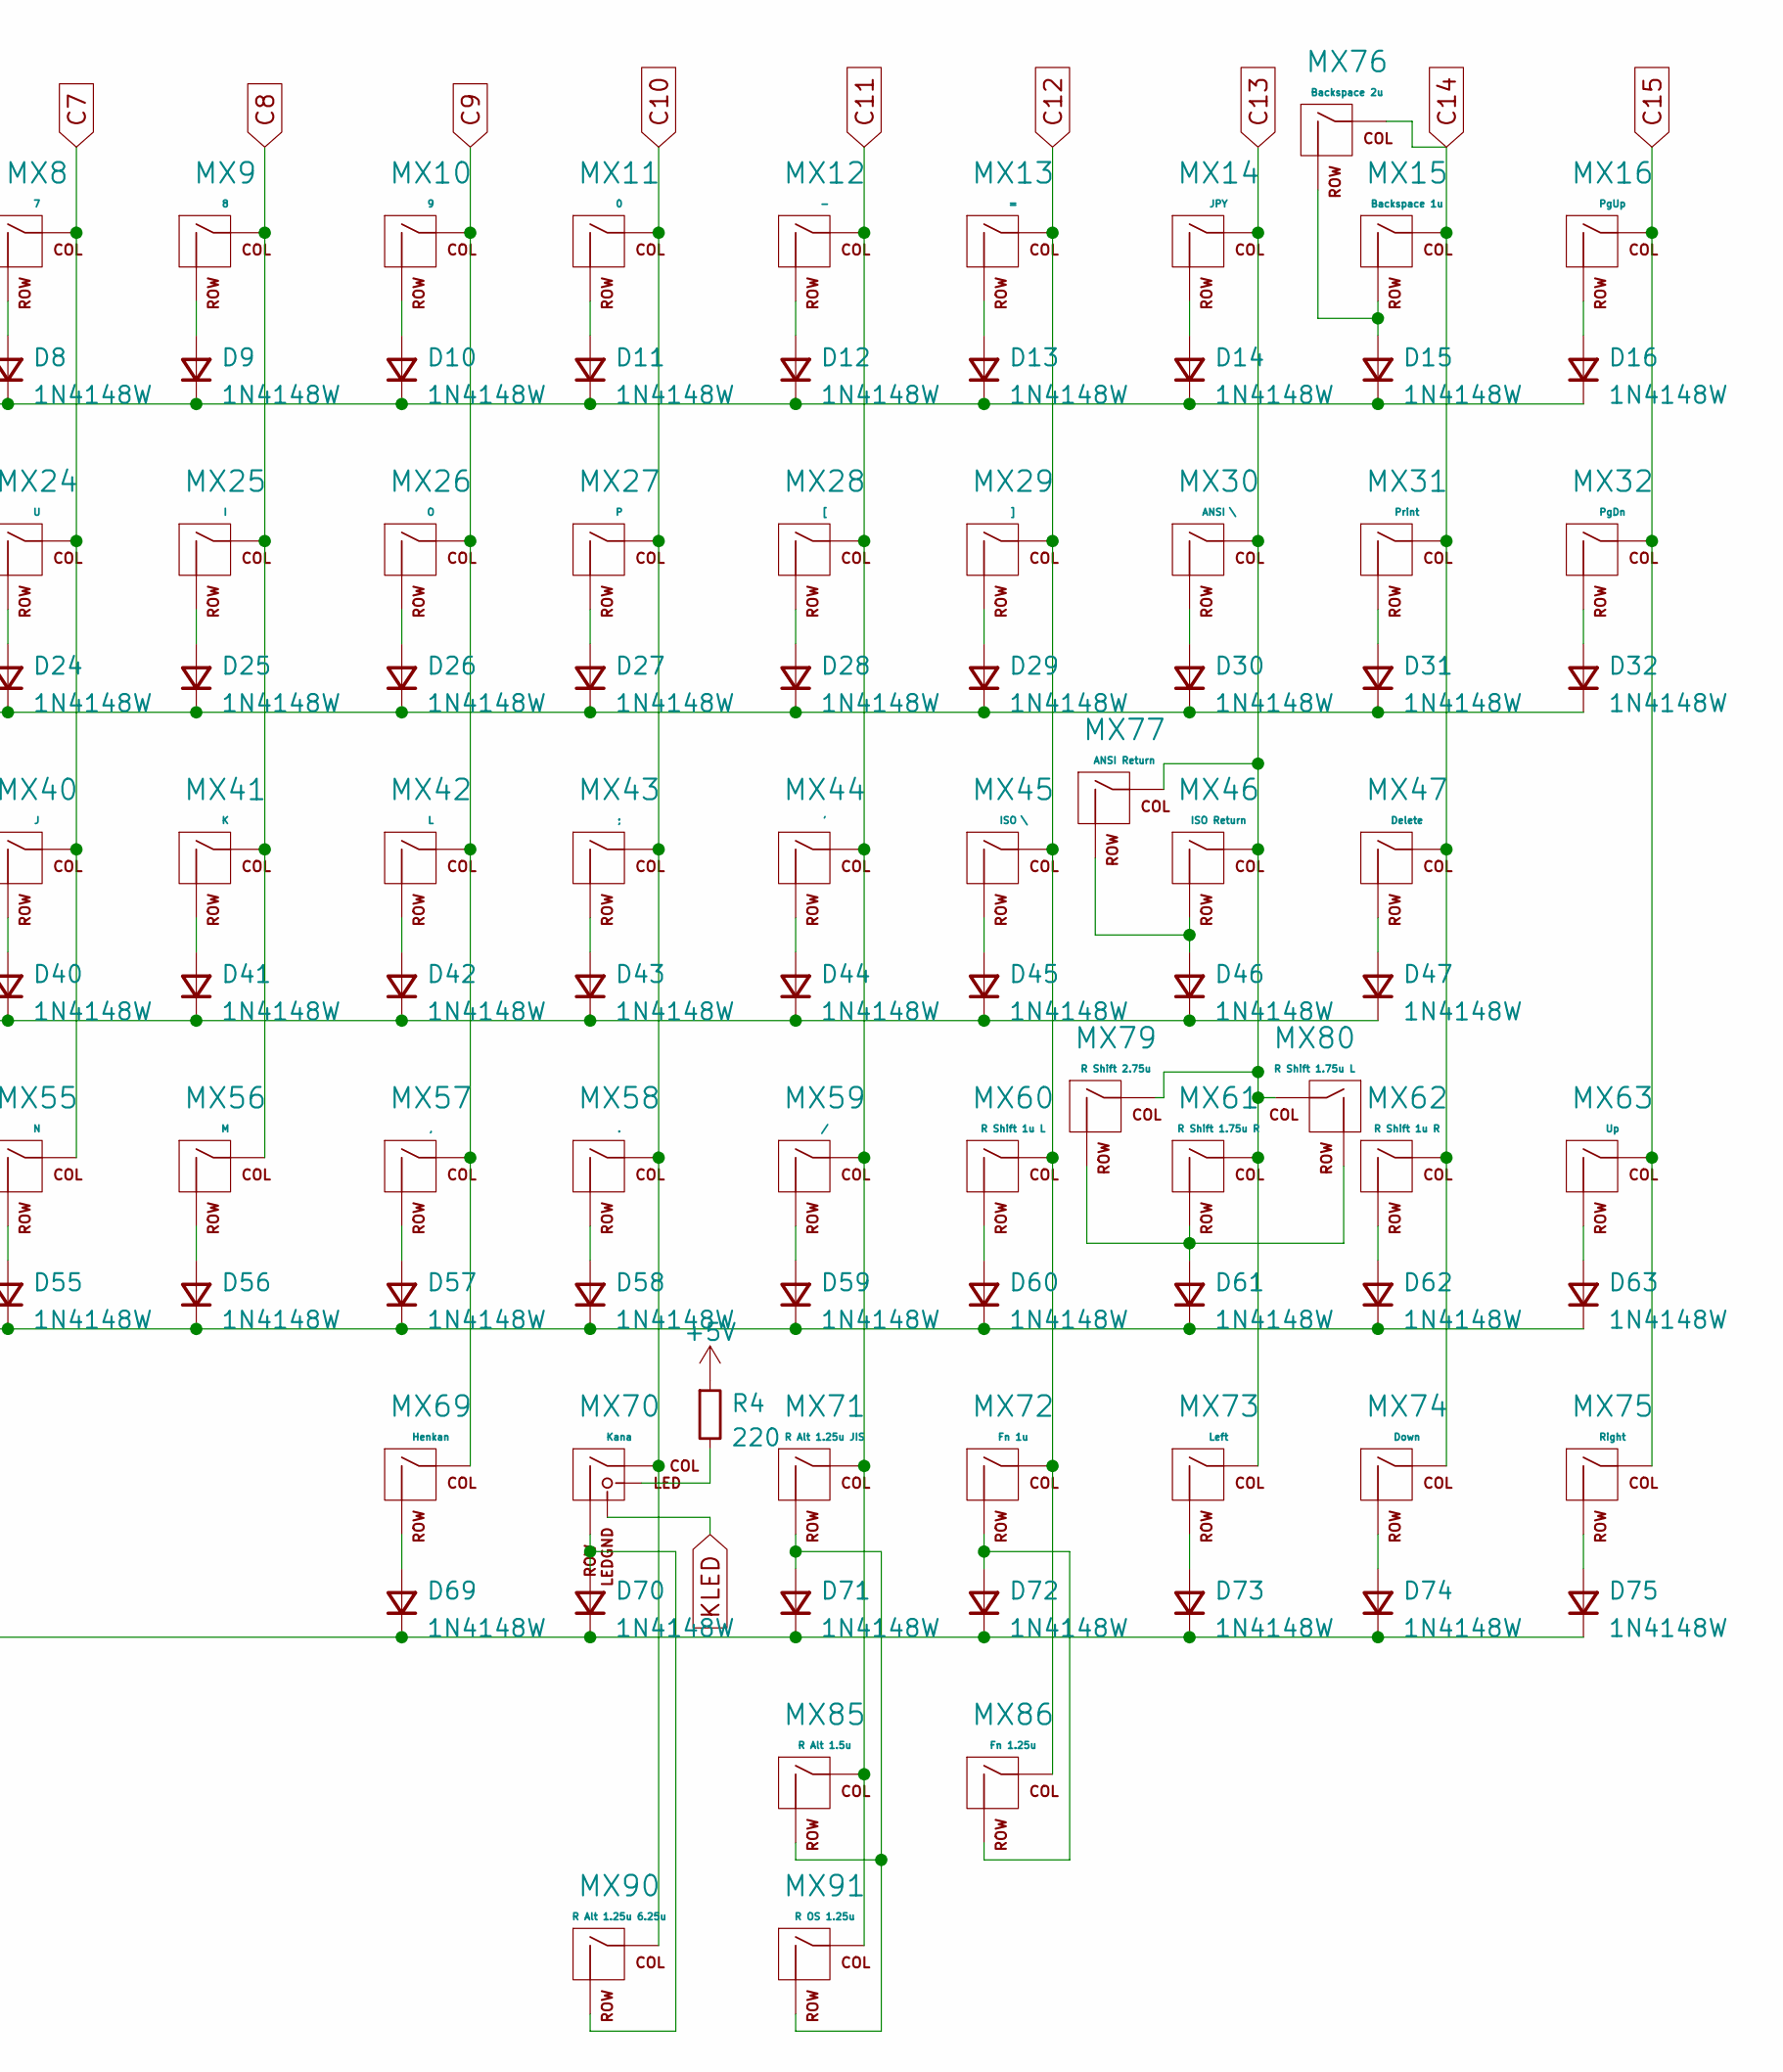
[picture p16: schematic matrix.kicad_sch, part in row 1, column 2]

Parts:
D1, D2, D3, D4, D5, D6, D7, D8, D9, D10, D11, D12, D13, D14, D15, D16, D17, D18, D19, D20, D21, D22, D23, D24, D25, D26, D27, D28, D29, D30, D31, D32, D33, D34, D35, D36, D37, D38, D39, D40, D41, D42, D43, D44, D45, D46, D47, D48, D49, D50, D51, D52, D53, D54, D55, D56, D57, D58, D59, D60, D61, D62, D63, D64, D65, D66, D67, D68, D69, D70, D71, D72, D73, D74, D75: 1N4148W; D_SOD-123; LCSC C81598
MX1: Esc; MXOnly-1U-NoLED
MX2: 1; MXOnly-1U-NoLED
MX3: 2; MXOnly-1U-NoLED
MX4: 3; MXOnly-1U-NoLED
MX5: 4; MXOnly-1U-NoLED
MX6: 5; MXOnly-1U-NoLED
MX7: 6; MXOnly-1U-NoLED
MX8: 7; MXOnly-1U-NoLED
MX9: 8; MXOnly-1U-NoLED
MX10: 9; MXOnly-1U-NoLED
MX11: 0; MXOnly-1U-NoLED
MX12: -; MXOnly-1U-NoLED
MX13: =; MXOnly-1U-NoLED
MX14: JPY; MXOnly-1U-NoLED
MX15: Backspace 1u; MXOnly-1U-NoLED
MX16: PgUp; MXOnly-1U-NoLED
MX17: Tab; MXOnly-1.5U-NoLED
MX18: Q; MXOnly-1U-NoLED
MX19: W; MXOnly-1U-NoLED
MX20: E; MXOnly-1U-NoLED
MX21: R; MXOnly-1U-NoLED
MX22: T; MXOnly-1U-NoLED
MX23: Y; MXOnly-1U-NoLED
MX24: U; MXOnly-1U-NoLED
MX25: I; MXOnly-1U-NoLED
MX26: O; MXOnly-1U-NoLED
MX27: P; MXOnly-1U-NoLED
MX28: [; MXOnly-1U-NoLED
MX29: ]; MXOnly-1U-NoLED
MX30: ANSI \; MXOnly-1.5U-NoLED
MX31: Print; MXOnly-1U-NoLED
MX32: PgDn; MXOnly-1U-NoLED
MX33: Caps Lock Standard; MXOnly-1.75U
MX34: A; MXOnly-1U-NoLED
MX35: S; MXOnly-1U-NoLED
MX36: D; MXOnly-1U-NoLED
MX37: F; MXOnly-1U-NoLED
MX38: G; MXOnly-1U-NoLED
MX39: H; MXOnly-1U-NoLED
MX40: J; MXOnly-1U-NoLED
MX41: K; MXOnly-1U-NoLED
MX42: L; MXOnly-1U-NoLED
MX43: ;; MXOnly-1U-NoLED
MX44: '; MXOnly-1U-NoLED
MX45: ISO \; MXOnly-1U-NoLED
MX46: ISO Return; MXOnly-ISO-ROTATED-ReversedStabilizers-NoLED
MX47: Delete; MXOnly-1U-NoLED
MX48: L Shift 2.25u; MXOnly-2.25U-NoLED
MX49: ISO R4 1u; MXOnly-1U-NoLED
MX50: Z; MXOnly-1U-NoLED
MX51: X; MXOnly-1U-NoLED
MX52: C; MXOnly-1U-NoLED
MX53: V; MXOnly-1U-NoLED
MX54: B; MXOnly-1U-NoLED
MX55: N; MXOnly-1U-NoLED
MX56: M; MXOnly-1U-NoLED
MX57: ,; MXOnly-1U-NoLED
MX58: .; MXOnly-1U-NoLED
MX59: /; MXOnly-1U-NoLED
MX60: R Shift 1u L; MXOnly-1U-NoLED
MX61: R Shift 1.75u R; MXOnly-1.75U-NoLED
MX62: R Shift 1u R; MXOnly-1U-NoLED
MX63: Up; MXOnly-1U-NoLED
MX64: L Ctrl 1.25u; MXOnly-1.25U-NoLED
MX65: L OS 1u JIS; MXOnly-1U-NoLED
MX66: L Alt 1.25u JIS; MXOnly-1.25U-NoLED
MX67: Muhenkan; MXOnly-1U-NoLED
MX68: Space 4.5u; MXOnly-4.5U-ReversedStabilizers-NoLED
MX69: Henkan; MXOnly-1.25U-NoLED
MX70: Kana; MXOnly-1.25U
MX71: R Alt 1.25u JIS; MXOnly-1.25U-NoLED
MX72: Fn 1u; MXOnly-1U-NoLED
MX73: Left; MXOnly-1U-NoLED
MX74: Down; MXOnly-1U-NoLED
MX75: Right; MXOnly-1U-NoLED
MX76: Backspace 2u; MXOnly-2U-NoLED
MX77: ANSI Return; MXOnly-2.25U-ReversedStabilizers-NoLED
MX78: Caps Lock Stepped; MXOnly-1.75U-STEPPED
MX79: R Shift 2.75u; MXOnly-2.75U-NoLED
MX80: R Shift 1.75u L; MXOnly-1.75U-NoLED
MX81: L Ctrl 1.5u; MXOnly-1.5U-NoLED
MX82: L OS 1u 7u; MXOnly-1U-NoLED
MX83: L Alt 1.5u 7u; MXOnly-1.5U-NoLED
MX84: Space 7u; MXOnly-7U-ReversedStabilizers-NoLED
MX85: R Alt 1.5u; MXOnly-1.5U-NoLED
MX86: Fn 1.25u; MXOnly-1.25U-NoLED
MX87: L OS 1.25u; MXOnly-1.25U-NoLED
MX88: L Alt 1.25u 6.25u; MXOnly-1.25U-NoLED
MX89: Space 6.25u; MXOnly-6.25U-ReversedStabilizers-NoLED
MX90: R Alt 1.25u 6.25u; MXOnly-1.25U-NoLED
MX91: R OS 1.25u; MXOnly-1.25U-NoLED
MX92: L Shift 1.25u; MXOnly-1.25U-NoLED
R4, R5: 220; R_0805_2012Metric; LCSC C17557

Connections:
+5V: R4.1, R5.1; also elsewhere on the board
C0: MX1.1 (COL), MX17.1 (COL), MX33.1 (COL), MX48.1 (COL), MX64.1 (COL), MX78.1 (COL), MX81.1 (COL), MX92.1 (COL); also elsewhere on the board
C1: MX2.1 (COL), MX18.1 (COL), MX34.1 (COL), MX49.1 (COL), MX65.1 (COL), MX82.1 (COL), MX87.1 (COL); also elsewhere on the board
C2: MX3.1 (COL), MX19.1 (COL), MX35.1 (COL), MX50.1 (COL), MX66.1 (COL), MX83.1 (COL), MX88.1 (COL); also elsewhere on the board
C3: MX4.1 (COL), MX20.1 (COL), MX36.1 (COL), MX51.1 (COL), MX67.1 (COL); also elsewhere on the board
C4: MX5.1 (COL), MX21.1 (COL), MX37.1 (COL), MX52.1 (COL); also elsewhere on the board
C5: MX6.1 (COL), MX22.1 (COL), MX38.1 (COL), MX53.1 (COL); also elsewhere on the board
C6: MX7.1 (COL), MX23.1 (COL), MX39.1 (COL), MX54.1 (COL), MX68.1 (COL), MX84.1 (COL), MX89.1 (COL); also elsewhere on the board
C7: MX8.1 (COL), MX24.1 (COL), MX40.1 (COL), MX55.1 (COL); also elsewhere on the board
C8: MX9.1 (COL), MX25.1 (COL), MX41.1 (COL), MX56.1 (COL); also elsewhere on the board
C9: MX10.1 (COL), MX26.1 (COL), MX42.1 (COL), MX57.1 (COL), MX69.1 (COL); also elsewhere on the board
C10: MX11.1 (COL), MX27.1 (COL), MX43.1 (COL), MX58.1 (COL), MX70.1 (COL), MX90.1 (COL); also elsewhere on the board
C11: MX12.1 (COL), MX28.1 (COL), MX44.1 (COL), MX59.1 (COL), MX71.1 (COL), MX85.1 (COL), MX91.1 (COL); also elsewhere on the board
C12: MX13.1 (COL), MX29.1 (COL), MX45.1 (COL), MX60.1 (COL), MX72.1 (COL), MX86.1 (COL); also elsewhere on the board
C13: MX14.1 (COL), MX30.1 (COL), MX46.1 (COL), MX61.1 (COL), MX73.1 (COL), MX77.1 (COL), MX79.1 (COL), MX80.1 (COL); also elsewhere on the board
C14: MX15.1 (COL), MX31.1 (COL), MX47.1 (COL), MX62.1 (COL), MX74.1 (COL), MX76.1 (COL); also elsewhere on the board
C15: MX16.1 (COL), MX32.1 (COL), MX63.1 (COL), MX75.1 (COL); also elsewhere on the board
CLED: MX33.4 (LEDGND), MX78.4 (LEDGND); also elsewhere on the board
KLED: MX70.4 (LEDGND); also elsewhere on the board
unnamed: D1.2 (A), MX1.2 (ROW)
unnamed: D2.2 (A), MX2.2 (ROW)
unnamed: D3.2 (A), MX3.2 (ROW)
unnamed: D4.2 (A), MX4.2 (ROW)
unnamed: D5.2 (A), MX5.2 (ROW)
unnamed: D6.2 (A), MX6.2 (ROW)
unnamed: D7.2 (A), MX7.2 (ROW)
unnamed: D8.2 (A), MX8.2 (ROW)
unnamed: D9.2 (A), MX9.2 (ROW)
unnamed: D10.2 (A), MX10.2 (ROW)
unnamed: D11.2 (A), MX11.2 (ROW)
unnamed: D12.2 (A), MX12.2 (ROW)
unnamed: D13.2 (A), MX13.2 (ROW)
unnamed: D14.2 (A), MX14.2 (ROW)
unnamed: D15.2 (A), MX15.2 (ROW), MX76.2 (ROW)
unnamed: D16.2 (A), MX16.2 (ROW)
unnamed: D17.2 (A), MX17.2 (ROW)
unnamed: D18.2 (A), MX18.2 (ROW)
unnamed: D19.2 (A), MX19.2 (ROW)
unnamed: D20.2 (A), MX20.2 (ROW)
unnamed: D21.2 (A), MX21.2 (ROW)
unnamed: D22.2 (A), MX22.2 (ROW)
unnamed: D23.2 (A), MX23.2 (ROW)
unnamed: D24.2 (A), MX24.2 (ROW)
unnamed: D25.2 (A), MX25.2 (ROW)
unnamed: D26.2 (A), MX26.2 (ROW)
unnamed: D27.2 (A), MX27.2 (ROW)
unnamed: D28.2 (A), MX28.2 (ROW)
unnamed: D29.2 (A), MX29.2 (ROW)
unnamed: D30.2 (A), MX30.2 (ROW)
unnamed: D31.2 (A), MX31.2 (ROW)
unnamed: D32.2 (A), MX32.2 (ROW)
unnamed: D33.2 (A), MX33.2 (ROW), MX78.2 (ROW)
unnamed: D34.2 (A), MX34.2 (ROW)
unnamed: D35.2 (A), MX35.2 (ROW)
unnamed: D36.2 (A), MX36.2 (ROW)
unnamed: D37.2 (A), MX37.2 (ROW)
unnamed: D38.2 (A), MX38.2 (ROW)
unnamed: D39.2 (A), MX39.2 (ROW)
unnamed: D40.2 (A), MX40.2 (ROW)
unnamed: D41.2 (A), MX41.2 (ROW)
unnamed: D42.2 (A), MX42.2 (ROW)
unnamed: D43.2 (A), MX43.2 (ROW)
unnamed: D44.2 (A), MX44.2 (ROW)
unnamed: D45.2 (A), MX45.2 (ROW)
unnamed: D46.2 (A), MX46.2 (ROW), MX77.2 (ROW)
unnamed: D47.2 (A), MX47.2 (ROW)
unnamed: D48.2 (A), MX48.2 (ROW), MX92.2 (ROW)
unnamed: D49.2 (A), MX49.2 (ROW)
unnamed: D50.2 (A), MX50.2 (ROW)
unnamed: D51.2 (A), MX51.2 (ROW)
unnamed: D52.2 (A), MX52.2 (ROW)
unnamed: D53.2 (A), MX53.2 (ROW)
unnamed: D54.2 (A), MX54.2 (ROW)
unnamed: D55.2 (A), MX55.2 (ROW)
unnamed: D56.2 (A), MX56.2 (ROW)
unnamed: D57.2 (A), MX57.2 (ROW)
unnamed: D58.2 (A), MX58.2 (ROW)
unnamed: D59.2 (A), MX59.2 (ROW)
unnamed: D60.2 (A), MX60.2 (ROW)
unnamed: D61.2 (A), MX61.2 (ROW), MX79.2 (ROW), MX80.2 (ROW)
unnamed: D62.2 (A), MX62.2 (ROW)
unnamed: D63.2 (A), MX63.2 (ROW)
unnamed: D64.2 (A), MX64.2 (ROW), MX81.2 (ROW)
unnamed: D65.2 (A), MX65.2 (ROW), MX82.2 (ROW), MX87.2 (ROW)
unnamed: D66.2 (A), MX66.2 (ROW), MX83.2 (ROW), MX88.2 (ROW)
unnamed: D67.2 (A), MX67.2 (ROW)
unnamed: D68.2 (A), MX68.2 (ROW), MX84.2 (ROW), MX89.2 (ROW)
unnamed: D69.2 (A), MX69.2 (ROW)
unnamed: D70.2 (A), MX70.2 (ROW), MX90.2 (ROW)
unnamed: D71.2 (A), MX71.2 (ROW), MX85.2 (ROW), MX91.2 (ROW)
unnamed: D72.2 (A), MX72.2 (ROW), MX86.2 (ROW)
unnamed: D73.2 (A), MX73.2 (ROW)
unnamed: D74.2 (A), MX74.2 (ROW)
unnamed: D75.2 (A), MX75.2 (ROW)
unnamed: MX33.3 (LED), MX78.3 (LED), R5.2
unnamed: MX70.3 (LED), R4.2
R0: D1.1 (K), D2.1 (K), D3.1 (K), D4.1 (K), D5.1 (K), D6.1 (K), D7.1 (K), D8.1 (K), D9.1 (K), D10.1 (K), D11.1 (K), D12.1 (K), D13.1 (K), D14.1 (K), D15.1 (K), D16.1 (K); also elsewhere on the board
R1: D17.1 (K), D18.1 (K), D19.1 (K), D20.1 (K), D21.1 (K), D22.1 (K), D23.1 (K), D24.1 (K), D25.1 (K), D26.1 (K), D27.1 (K), D28.1 (K), D29.1 (K), D30.1 (K), D31.1 (K), D32.1 (K); also elsewhere on the board
R2: D33.1 (K), D34.1 (K), D35.1 (K), D36.1 (K), D37.1 (K), D38.1 (K), D39.1 (K), D40.1 (K), D41.1 (K), D42.1 (K), D43.1 (K), D44.1 (K), D45.1 (K), D46.1 (K), D47.1 (K); also elsewhere on the board
R3: D48.1 (K), D49.1 (K), D50.1 (K), D51.1 (K), D52.1 (K), D53.1 (K), D54.1 (K), D55.1 (K), D56.1 (K), D57.1 (K), D58.1 (K), D59.1 (K), D60.1 (K), D61.1 (K), D62.1 (K), D63.1 (K); also elsewhere on the board
R4: D64.1 (K), D65.1 (K), D66.1 (K), D67.1 (K), D68.1 (K), D69.1 (K), D70.1 (K), D71.1 (K), D72.1 (K), D73.1 (K), D74.1 (K), D75.1 (K); also elsewhere on the board

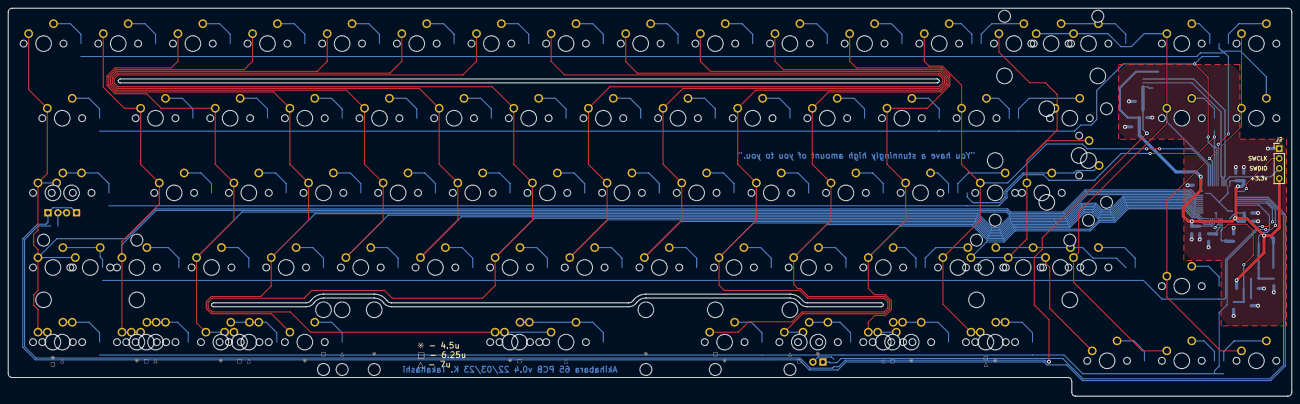
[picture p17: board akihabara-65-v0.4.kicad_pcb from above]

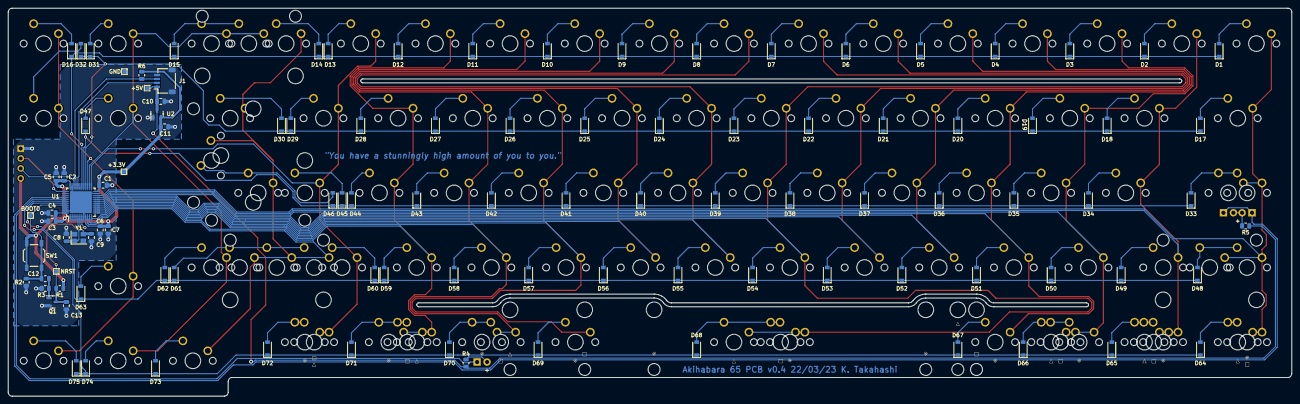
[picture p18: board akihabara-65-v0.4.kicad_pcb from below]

Board: 2 copper layers, 327.6 x 99.0 mm, 198 parts (105 on the bottom side), 112 nets.

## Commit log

2022-03-17 v4.0 Initial
    [PCB Outline.dxf, Switch Positioning.dxf, akihabara-65-bom.csv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]
2022-03-17 added images, updated readme, updated PCB
    [akihabara-65-plate-universal-v0.4.dxf, akihabara-65-v0.4.kicad_pcb]
2022-03-21 add gitignore
    [akihabara-65-v0.4.kicad_pcb, akihabara-65-v0.4.kicad_sch]
2022-03-21 PCB update
    Added bottom row indicators on silkscreen.
    [akihabara-65-v0.4.kicad_pcb]
2022-03-24 PCB changes, readme, case files now added
    - Changed MCU footprint from LQFP-48 to LQFP-48 + UFQFPN-48 dual footprint to combat MCU shortage
    - PCB production files are for STM32F072CBUx; edit BOM, CPL, and paste layer if you want SMT assembly for an STM32F072CBTx
    - STEP files and their associated technical drawings are now included for the case and plate
    - Added more images, updated existing images
    - Updated readme
    [akihabara-65-case-assembly-v0.4.step, akihabara-65-case-bottom-v0.4.step, akihabara-65-case-top-v0.4.step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]
